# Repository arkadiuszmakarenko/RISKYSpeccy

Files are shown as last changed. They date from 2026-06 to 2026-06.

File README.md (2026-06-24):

# RISKY Speccy

A CH32V307 RISC-V cartridge that plugs into the ZX Spectrum edge connector
and provides:

- **Snapshot loader** — load `.z80` v1/v2/v3 files from USB storage and
  launch them with full register restore.
- **Tape player** — play `.tap` / `.tzx` files by injecting the EAR signal
  directly onto the data bus, compatible with the Spectrum's built-in tape
  loader.
- **Interface 2 ROM cart** — load `.rom` / `.bin` files (up to 16 KB) as an
  Interface 2 style cartridge ROM, mapped into the Spectrum's 0x0000-0x3FFF
  region.
- **On-screen UI** — full-screen file browser and VT100-compatible terminal
  rendered by the CH32 onto the ZX screen via the NMI mailbox, without any
  Z80 cooperation.

See [docs/](docs/) for architecture and subsystem documentation.

---

## Repository layout

```
board/          KiCad schematic and PCB design
docs/           Architecture and subsystem documentation
firmware/       CH32 firmware source
  Core/         WCH RISC-V core support files
  Debug/        UART debug driver
  Ld/           Linker script
  Peripheral/   CH32V30x peripheral drivers
  Startup/      Startup assembly
  User/         Application code (main subsystems)
  zx_src/       Z80-side cart ROM firmware (SDCC)
Makefile        Root build file (builds everything)
```

---

## Building

### Prerequisites

**CH32 RISC-V toolchain** (WCH GCC 12):

Download from [MounRiver Studio](http://www.mounriver.com/) or extract the
standalone toolchain archive.  The default path expected by the Makefile is:

```
~/RISC-V_Embedded_GCC12
```

**Z80 toolchain** (for the `zx_src` sub-firmware):

```
sudo apt install sdcc
```

The `sdasz80` assembler is included with SDCC.  GNU `objcopy`, `od`, and
`awk` must also be available (standard on most Linux systems).

### Build

```sh
make
```

Override the toolchain path if needed:

```sh
make TOOLCHAIN_DIR=/path/to/RISC-V_Embedded_GCC12
```

Useful targets:

```sh
make help                # full list of targets
make build-all-versions  # bootloader + both app variants + combined image
make versions            # show all output artifact paths
make clean
```

Build outputs land in `build/`.

### Continuous integration (GitHub Actions)

A workflow at [`.github/workflows/build.yml`](.github/workflows/build.yml)
builds the firmware on every push, pull request, tag, and manual dispatch.
It:

- installs the WCH RISC-V toolchain (V2.10) and SDCC from `apt`
- runs `make` at the repo root
- verifies that all expected artifacts (`Bootloader.bin`, `RISKYSpeccy.bin`,
  `RISKYZXS.UPD`, `RISKYZXS_COMBINED.bin`) are produced
- checks that the bootloader and app-update binaries fit their respective
  flash regions
- uploads the binaries as a workflow artifact
  (`RISKYZXSpectrum-firmware`, retained for 90 days) and the listings/maps
  as a separate logs artifact
- on tag pushes (`v*`) and on `release` events, attaches the user-facing
  binaries (`*.bin` / `*.UPD` at the top of `build/`) to a GitHub Release

The default `latest` release is marked as prerelease and is updated on
every non-PR run; tagged builds (`v1.2.3`, etc.) become stable releases.
No secrets are required — the workflow uses the default `GITHUB_TOKEN`
to create/update releases.

### Flashing options

| Mode | Command | Output | When to use |
|---|---|---|---|
| **Combined** (default) | `make flash` | `build/RISKYZXS_COMBINED.bin` | Fresh cartridge setup or bootloader + app in one shot |
| **Standalone (no BL)** | `make flash-standalone` | `build/RISKYSpeccy.bin` | Development or single-firmware deployment |
| **Bootloader only** | `make flash-bootloader` | `build/bootloader/Bootloader.bin` | Bootloader maintenance / recovery |
| **App via USB** | _(copy to USB drive)_ | `build/RISKYZXS.UPD` | After bootloader is installed |

The Linux `make flash*` targets drive a **WCH-LinkE** via OpenOCD.

#### Programming on Windows with WCH tools

1. Install [WCHISPTool](https://www.wch.cn/downloads/WCHISPTool_Setup_exe.html)
   and the **WCH-LinkE** USB driver (WCH provides a signed INF/VCP driver
   bundle — let the installer do it, or grab the driver from the
   MounRiver Studio distribution).
2. Connect the **WCH-LinkE** to the cartridge's SWD header (SWDIO / SWCLK /
   GND).  Power the Spectrum so the CH32V307 is alive on the edge connector.
3. Launch **WCHISPTool** and pick the chip family **CH32V30x** (the
   CH32V307 lives in this group).
4. In the device list, select the WCH-LinkE you just plugged in.  The tool
   should show the chip's `Device ID` once it talks to the target.
5. Click **...** next to the file box and point it at the build output:
   - `build/RISKYZXS_COMBINED.bin` — bootloader + application in one shot
     (use the **.bin** image, not `.elf`/`.hex`)
   - `build/RISKYSpeccy.bin` — application only (no bootloader)
   - `build/bootloader/Bootloader.bin` — bootloader only
6. Set the start address to **`0x08000000`** for any of the above.
7. Enable **"Erase before program"** and **"Verify after program"**, then
   click **Download** (or press F5).  Progress shows in the status bar;
   "Success" means programming finished and verified.

#### Updating the application via USB (no programmer)

For the **app-via-USB** path, the bootloader must already be installed on
the cartridge (use the WCHISPTool flow above once with the combined or
bootloader image to put it in place).

1. Copy `build/RISKYZXS.UPD` to the **root** of a **FAT12/FAT16/FAT32**
   formatted USB drive.
2. Insert the USB drive into the cartridge's USB port.
3. To **force IAP mode** (e.g. if the application is wedged and you want
   to reflash), fit a jumper across the **SWDIO / SWCLK** header pins
   before powering on.
4. Power on (or reset) the cartridge. The Ready LED should flash 3 times.
   The bootloader detects the drive and programs the application. If
   programming was successful, the Ready LED will flash slowly 10 times.
   If unsuccessful, it will start rapidly flashing.

See [docs/bootloader.md](docs/bootloader.md) for the full update flow,
state-machine details, and recovery options.

---

## CH32V303 RAM / FLASH split

The CH32V303 lets you trade FLASH for RAM (or vice versa) via the
**SRAM_CODE_MODE** field — bits `[7:6]` of the USER option byte at
`0x1FFFF802`.  The four available splits are:

| SRAM_CODE_MODE | FLASH  | RAM |
|---|---|---|
| `00` | 192 KB | 128 KB |
| `01` | 224 KB |  96 KB |
| `10` | 256 KB |  64 KB |
| `11` | 288 KB |  32 KB |

This project uses **`00`** (192 KB FLASH + 128 KB RAM).  **You must set
this split before flashing the firmware**, otherwise RAM and FLASH regions
will not match the linker script and the firmware will not run.

### Setting the split with WCHISPTool (recommended)

This is the easiest method and requires only the WCH-LinkE programmer.

1. Open **WCHISPTool**, select chip family **CH32V30x**, and connect to the
   target (same as for flashing firmware — see [Flashing options](#flashing-options)).
2. Switch to the **Config** (or **Option Byte**) tab.
3. Locate the **SRAM_CODE_MODE** field (labelled `USER[7:6]` in some
   versions).
4. Select **`00`** from the drop-down to configure 192 KB FLASH + 128 KB RAM.
5. Click **Program** (or **Download**) to write the option byte.
6. Power-cycle or reset the board.  The new split is now active and you can
   proceed to flash the firmware.

### Setting the split with the Makefile (Linux + WCH-LinkE)

The repository provides Makefile targets that set the split and reboot the
chip in one step.  This is the quickest path on Linux.

| Command | Description |
|---|---|
| `make split-info` | Read current option bytes (uses `minichlink -i`) |
| `make split-set` | Set the split to `MODE=0` (192K FLASH + 128K RAM) via minichlink |
| `make split-set MODE=0 SPLIT_TOOL=openocd` | Same, but uses OpenOCD |
| `make split-set-minichlink MODE=N` | Set split via minichlink, `N` = 0..3 |
| `make split-set-openocd MODE=N` | Set split via OpenOCD, `N` = 0..3 |

`MODE` values: `0` = 192K FLASH + 128K RAM, `1` = 224K + 96K, `2` = 256K + 64K,
`3` = 288K + 32K.  **This project requires `MODE=0`.**

```sh
# Default (recommended): mode 0 via minichlink
make split-set

# Mode 0 via OpenOCD
make split-set SPLIT_TOOL=openocd

# Power-cycle the board, then flash firmware
make flash
```

> After writing, power-cycle the board before flashing firmware.

### Setting the split with OpenOCD / WCH-LinkE on Linux (manual)

```sh
openocd -f interface/wch-riscv.cfg \
        -c "init; halt; \
            flash write_word 0x1FFFF802 0xC03F; \
            reset; exit"
```

The half-word `0xC03F` encodes USER byte `0x3F` (`SRAM_CODE_MODE = 00`,
all other bits at default) in the low byte and its complement `0xC0` in
the high byte, as required by the option byte format.

> After writing, power-cycle the board before flashing firmware.

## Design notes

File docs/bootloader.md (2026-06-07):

# Bootloader Architecture

## Overview

The RISKY Speccy bootloader is a specialized in-application programming (IAP) monitor that:

1. **Boots first** from flash offset `0x00000000`
2. **Manages application lifetime** — validates, jumps to, and recovers from invalid application states
3. **Provides USB-based firmware updates** via Petit FatFS + USB MSC
4. **Implements robust USB polling** with automatic attach detection and fallback enumeration
5. **Protects itself** — hard-wired 16 KB memory boundary ensures app writes never corrupt bootloader load image

---

## Memory Map

### Bootloader Regions

```
FLASH Memory (CH32V30x_D8, SRAM_CODE_MODE=00 → 192 KB):
┌─────────────────────────┬─────────────────────────────────────────┐
│ Bootloader              │ Application + IAP Update Slot           │
│ 0x00000000..0x00003FFF  │ 0x00004000..0x0002FFFF                  │
│ (16 KB reserved)        │ (176 KB available)                      │
└─────────────────────────┴─────────────────────────────────────────┘

RAM Memory (128 KB):
┌────────────────────────────────────────────────────────────────┐
│ Stack, data, BSS for bootloader + USB host + FAT subsystems   │
│ 0x20000000..0x2001FFFF                                         │
└────────────────────────────────────────────────────────────────┘
```

> **Note:** Total flash and RAM size are governed by `SRAM_CODE_MODE` (USER[7:6]
> of the option byte at `0x1FFFF802`). The project targets mode `00`
> (192 KB FLASH + 128 KB RAM). All three linker scripts must agree on this
> setting — the chip-wide option byte cannot be different for bootloader and
> application.

### Bootloader Linker Script

**File:** `Bootloader/Ld/Link.ld`

Key settings:

- **BOOT_FLASH:** `ORIGIN=0x00000000, LENGTH=16K` — hard boundary on loadable sections
- **RAM:** `ORIGIN=0x20000000, LENGTH=128K`
- **All `.text`, `.data` LMA mapped to BOOT_FLASH** — linker enforces overflow error if bootloader > 16 KB
- **PROVIDE(`_bootloader_limit` = 0x00004000)** — marks app start boundary
- **PROVIDE(`_flash_limit` = 0x00030000)** — total on-chip flash end (192 KB for `SRAM_CODE_MODE=00`; would be 0x00038000 = 224 KB in mode 01), used by IAP for upper-bound checks on erase/write operations

### Application Linker Script (Bootloader-linked variant)

**File:** `firmware/Ld/Link.ld`

- **FLASH:** `ORIGIN=0x00004000, LENGTH=176K` — app linked with 0x4000 base, fills the rest of the 192 KB flash
- **RAM:** `ORIGIN=0x20000000, LENGTH=128K`
- Final `.data` LMA placed in FLASH for proper ROM image

### Application Linker Script (Standalone variant)

**File:** `firmware/Ld/Link_standalone.ld`

- **FLASH:** `ORIGIN=0x00000000, LENGTH=192K` — full chip, no bootloader
- **RAM:** `ORIGIN=0x20000000, LENGTH=128K`
- Used for development or direct flash without IAP

---

## Boot Flow

### Startup Sequence (main.c)

```
1. Delay_Init()          -- Setup system timer
2. USART_Printf_Init()   -- Configure debug UART
3. Enable GPIOA + AFIO clocks
4. GPIO_PinRemapConfig(SWJ_Disable) -- Release PA13/PA14 from SWD alternate function
5. PA13 → push-pull output, driven LOW
   PA14 → input pull-up
6. Check PA14 level
   └─ PA14 LOW (jumpered to PA13): Enter IAP mode
      ├─ IAP_Initialization()  -- USB host, RCC, global state
      ├─ PA8 → open-drain output (LED)
      ├─ blinkLed()
      └─ IAP_Main_Deal() loop (USB update flow)
   └─ PA14 HIGH (no jumper): Jump to application
      └─ IAP_Jump_APP() 
```

### State Machine (IAP_Main_Deal in usb_host_iap.c)

**Goal:** Read file from USB FAT drive, program to flash, verify, and jump to app.

```
┌─ IAP_USBH_PreDeal()
│  ├─ Check root hub port status
│  ├─ If already attached (hardware flag set) but no connect event fired
│  │  └─ Synthesize connect event (handles pre-inserted drives)
│  ├─ Enumerate device
│  │  ├─ Get descriptor
│  │  ├─ Set device address
│  │  ├─ Get config descriptor
│  │  ├─ Parse MSC interface + bulk endpoints
│  │  └─ Return DEF_SUCCESS or error
│  └─ State → ROOT_DEV_SUCCESS = ready
│
├─ PFF_Check_And_Mount()
│  ├─ Initialize disk subsystem (SCSI READ CAPACITY)
│  ├─ pf_mount() — mount FAT filesystem
│  └─ Return 0 if mounted, else error
│
├─ pf_open("RISKYZXS.UPD")
│  └─ If file not found → retry or wait
│
├─ Read file in chunks
│  ├─ pf_read() with adaptive retries
│  ├─ On FR_DISK_ERR:
│  │  ├─ Reduce chunk size (512 → 256 → 128 → 64 bytes)
│  │  ├─ Reset disk state machine
│  │  ├─ Re-mount filesystem
│  │  ├─ Re-seek to offset
│  │  └─ Retry pf_read()
│  └─ Load into RAM buffer
│
├─ IAP_Flash_Program()
│  ├─ Erase pages as needed
│  ├─ Write aligned 256-byte blocks
│  ├─ Verify keys (flash runaway protection)
│  └─ Return 0 if success
│
├─ Verify by re-opening file
│  ├─ pf_read() entire file again
│  ├─ Compare each byte with flash
│  └─ If match → Vfy OK; else Vfy FAIL
│
└─ If success: IAP_Jump_APP()
   ├─ Set software interrupt (Software_IRQn)
   ├─ Trigger it
   ├─ CPU jumps to app @ 0x08004000
```

---

## USB Host & FAT Integration

### USB Host Stack

**File:** `Bootloader/User/USB_Host/ch32v30x_usbfs_host.c`

- **USBFSH_CheckRootHubPortStatus()** — polls device attachment state
- **USBFSH_EnableRootHubPort()** — waits for post-reset device detection
- **USBFSH_GetDeviceDescr()** — retrieves device descriptor with retries
- **USBFSH_CtrlTransfer()** — sends control requests (SET ADDR, GET CONFIG)
- **USBFSH_SendEndpData() / GetEndpData()** — bulk data transfer with NAK/STALL handling

**Key Tuning:**
- Bulk endpoint timeout: `200 ms` (allows NAK retry without aborting)
- Reset recovery: `DEF_RE_ATTACH_TIMEOUT = 100 ms`

### Petit FatFS Integration

**File:** `Bootloader/User/Pff/diskio.c`

- **disk_initialize()** — SCSI READ CAPACITY to detect drive presence
- **disk_readp()** — sector read with:
  - CBW (Command Block Wrapper) send
  - Data phase
  - CSW (Command Status Wrapper) receive
  - Multi-stage retry on error (TUR, reset, re-init, final fail print with sense data)

**Key Features:**
- Adaptive chunk size: starts at 512 bytes, halves on error
- Sense data logging: prints ASC/ASCQ for SCSI diagnostics
- Geometry detection: logs last LBA and block size on failure

---

## Recovery & Fallback Mechanisms

### Pre-inserted USB Drive Detection

**Problem:** If USB is already in the slot at power-on, the attach interrupt may not fire, leaving the device stuck in idle state.

**Solution (firmware/User/FATFS/usb_disk.c and Bootloader):**
```c
hw_attached = ((USBFSH->MIS_ST & USBFS_UMS_DEV_ATTACH) != 0) ? 1 : 0;
if ((ret == ROOT_DEV_FAILED) && hw_attached &&
    (RootHubDev[usb_port].bStatus != ROOT_DEV_SUCCESS)) {
    ret = ROOT_DEV_CONNECTED;  // Force enum
}
```

### Invalid Application / No Jumper

If the jumper is absent at power-on, the bootloader jumps unconditionally to the application address (`0x08004000`). If no valid firmware is present at that address, the behaviour is undefined — the chip will fault or spin. In this case, refit the jumper and power-cycle to re-enter IAP mode and re-flash.

### Persistent USB Retry Loop

**Problem:** Firmware terminal used to spin `ret=255` infinitely if USB never achieved ready state.

**Solution (firmware/User/zx_terminal.c):**
```c
/* Poll with timeout + adaptive re-init on default state */
for (tries = 0; tries < 100; ++tries) {
    usb_ret = USBH_PreDeal();
    if (usb_ret == DEF_SUCCESS) break;
    Delay_Ms(20u);
}
if (usb_ret == DEF_DEFAULT) {
    ClearUSB();  // Reset state
    USB_Initialization();
    Delay_Ms(50u);
    /* Retry briefly */
    for (tries = 0; tries < 50; ++tries) {
        usb_ret = USBH_PreDeal();
        if (usb_ret == DEF_SUCCESS) break;
        Delay_Ms(20u);
    }
}
```

---

## Build Targets

### Root Makefile (Makefile)

**Key rules:**

| Target | Effect |
|---|---|
| `make bootloader` | Compiles and links Bootloader/.* → build/bootloader/Bootloader.elf/.bin |
| `make app-bootloader` | Links app at 0x4000 → build/RISKYZXS.UPD |
| `make app-standalone` | Links app at 0x0000 → build/RISKYSpeccy.bin |
| `make combine` | Pads to 16 KB + cat bootloader.bin + app.bin → build/RISKYZXS_COMBINED.bin |
| `make all` or `make build-all-versions` | Build all four above |
| `make flash` | Flash combined image to 0x0000 |
| `make flash-bootloader` | Flash bootloader only |
| `make flash-app-upd` | Flash app update image to 0x4000 |
| `make flash-standalone` | Flash standalone app to 0x0000 |

### Bootloader Compile Settings

- **Optimization:** `-Os` (size) to fit 16 KB boundary
- **Debug logs:** Controlled by `DEF_DEBUG_PRINTF` in `Bootloader/User/USB_Host/usb_host_config.h`
- **Compiler flags:** Same RISC-V ABI as app, but no `-Ofast`

---

## Testing & Validation

### Manual Testing Checklist

1. **Boot to IAP with PA13/PA14 jumpered**
   - Fit jumper across SWDIO (PA13) and SWCLK (PA14) header pins
   - `Initializing GPIO for IAP mode detection...` then `Initializing IAP subsystem...` prints on USART1
   - LED blinks
   - Prompt appears on ZX screen

2. **USB enumeration**
   - Insert USB drive with test file
   - Press Enter
   - `USB dev In.` and `USB Port 00 Device Enumeration Succeed` print

3. **File programming**
   - Check `IAP: XXXX bytes` matches file size
   - Verify no read errors or `Len err` prints

4. **Reboot behavior**
   - After successful upgrade, reboot without USB
   - App starts directly (no IAP prompt)
   - LED stops blinking

5. **Recovery from missing/corrupt firmware**
   - Fit the jumper across SWDIO/SWCLK
   - Power-cycle the cartridge
   - Bootloader enters IAP mode (jumper present)
   - Re-flash via USB drive

### Automated Build Validation

```sh
make clean
make build-all-versions
make versions  # Print all artifact paths
# Inspect build/bootloader/Bootloader.siz — should be < 16 KB
# Inspect build/RISKYZXS.UPD — should match firmware size
```

---

## Known Limitations & Future Work

1. **Single USB device** — Only one MSC drive supported at a time
2. **FAT cluster chain** — Petit FatFS may struggle with highly fragmented drives
3. **No rollback** — If verification fails, no automatic revert to previous version
4. **LED blink pattern** — Currently just slow blink; could encode state more clearly (e.g., rapid on error)
5. **Timeout configurable** — USB timeouts are hardcoded; could be made tunable via config sector

---

## References

- CH32V30x Datasheet: `http://www.wch.cn/downloads/CH32V30xRM_PDF.html`
- Petit FatFS: `http://elm-chan.org/fsw/ff/00index_p.html`
- USB Mass Storage Class: USB-IF BOT Specification
- WCH OpenOCD Setup: `http://www.mounriver.com/`

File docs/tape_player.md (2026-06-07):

# Tape Player — TAP and TZX Playback

This document explains how `.tap` and `.tzx` tape image files are loaded and
played back, and how the EAR signal is injected onto the ZX Spectrum data bus
by the CH32V307 cartridge MCU.

---

## Hardware overview

The ZX Spectrum reads the cassette EAR signal via an `IN A,(#FE)` instruction.
The ULA drives the data bus with the current tape level on **bit 6**.  The
cartridge exploits this by intercepting every `IN A,(#FE)` and driving the
data bus itself with the current playback state.

| Signal | GPIO | Direction | Purpose |
|---|---|---|---|
| /IORQ  | GPIOC Pin 8  | Input floating → EXTI9_5 trigger | Fires on every I/O cycle  |
| /RD | GPIOB Pin 5  | Input floating | Distinguishes IN from OUT / INTACK |
| A0 | GPIOE Pin 0  | Input floating | Low = ULA port (tape/keyboard); high = other |
| Data | GPIOD[7:0] | Input / output PP | Driven during IN A,(#FE) only |

**Key principle**: the CH32 does not generate an audio signal — it drives the
Z80 data bus directly.  When the Spectrum ROM tape loader executes
`IN A,(#FE)`, the CH32 asserts the data bus with the current EAR bit value.
The ROM loader reads the bit and advances its own sync/data detection logic
exactly as it would from a real tape.

> **Bus-contention note**: the ULA also drives the data bus during
> `IN A,(#FE)`.  While the IORQ ISR is active there is a brief period of
> contention between the CH32 push-pull output and the ULA output.
> This is an experimental implementation; it is tolerable on hardware that
> accepts brief contention, but not guaranteed safe on all boards.

---

## File formats

### TAP

A `.tap` file is a sequence of raw TAP blocks with no global header.
Each block is:

```
Offset  Size  Content
  0       2   Block length N (little-endian, does not include these 2 bytes)
  2       N   Block data (first byte is the ZX flag byte: 0x00=header, 0xFF=data)
```

The flag byte determines the pilot pulse count:
- `0x00` (program/header block): **8064 full pilot pulses**
- any other value (data block): **3220 full pilot pulses**

### TZX

A `.tzx` file begins with the 10-byte global header:

```
Offset  Size  Content
  0       7   "ZXTape!" (ASCII, no null terminator)
  7       1   0x1A (end-of-text marker)
  8       1   Major version (must be 1)
  9       1   Minor version
```

followed by a sequence of typed blocks.  The player supports:

| Block ID | Name | Handling |
|---|---|---|
| `0x10` | Standard speed data | Converted to a TAP block in memory  |
| `0x20` | Pause | Skipped (converted blocks carry their own inter-block pause) |
| `0x21` | Group start | Skipped (metadata) |
| `0x22` | Group end | Skipped (metadata) |
| `0x30` | Text description | Skipped (metadata) |
| `0x31` | Message block | Skipped (metadata) |
| `0x32` | Archive info | Skipped (metadata) |
| `0x33` | Hardware type | Skipped (metadata) |
| `0x35` | Custom info | Skipped (metadata) |
| `0x5A` | Glue block | Skipped |
| any other | Turbo / pure tone / CSW / direct | **Rejected** — load fails |

TZX conversion is performed in-place inside the 50 KB tape buffer
(`TAP_ConvertTzxInPlace`): standard-speed blocks (`0x10`) are rewritten as
plain TAP blocks at the start of the buffer, metadata blocks are discarded,
and the resulting TAP stream length is stored in `s_tap_total`.

---

## Tape timing

All timings are expressed in **Z80 T-states at 3.5 MHz**.

| Signal segment | Duration (T-states) | TIM2 ticks (×20) |
|---|---:|---:|
| Pilot half-pulse | 2168 | 43 360 |
| Sync first half |  667 | 13 340 |
| Sync second half |  735 | 14 700 |
| Bit-0 half-pulse |  855 | 17 100 |
| Bit-1 half-pulse | 1710 | 34 200 |
| Inter-block pause | ~1 s (≈1660 pilot-half intervals) | — |

**Timer clock**: TIM2 prescaler = 1 (÷2) → 144 MHz / 2 = **72 MHz**.  One
T-state ≈ 72 MHz / 3.5 MHz = **20.57 ticks**, rounded to 20.  The resulting
~3 % timing error is well within the ±10 % tolerance of the ZX ROM tape
loader.

Each bit is transmitted as **two equal half-pulses**: EAR toggles at the start
of the first half and again at the start of the second half.  Bits are sent
**MSB first** within each byte.

---

## State machine

`TAP_TimerISR` (TIM2 one-shot update interrupt, VTF slot 2) drives the
following state machine.  On every fire:
1. The current EAR level (`s_ear_bit`) is toggled (except during `TAP_PAUSE`).
2. The next one-shot period is loaded and TIM2 is restarted.

```
           TAP_IDLE
               │  TAP_Player_Start() + TAP_NextBlock()
               ▼
           TAP_PILOT  ─── decrement s_pilot_half_rem
               │             (8064 × 2 or 3220 × 2 half-pulses)
               │  last half-pulse
               ▼
           TAP_SYNC1  ──► TAP_SYNC2
                               │
                               ▼
                      TAP_DATA_FIRST_HALF ◄────────────────┐
                               │                           │
                               ▼                           │ next bit
                      TAP_DATA_SECOND_HALF ─── advance bit─┘
                               │
                               │  block exhausted
                               ▼
                           TAP_PAUSE  ─── count down ~1 s
                               │
                ┌──────────────┴──────────────┐
                │  more blocks                │  no more blocks
                ▼                             ▼
            TAP_PILOT                     TAP_DONE
                                          (ISRs disabled)
```

---

## Two-ISR architecture

### TAP_TimerISR — EAR signal generator

- **Interrupt**: TIM2 update (one-shot mode), **VTF slot 2**, priority 2.
- **Responsibility**: advance the state machine and toggle `s_ear_bit`.
- **Never** touches the data bus — it only updates the `s_ear_bit` variable.
- Arms the next one-shot by writing `TIM2->ATRLR` and setting `TIM_CEN`.

### TAP_IorqISR — Bus injection

- **Interrupt**: EXTI9_5 on PC8 (`/IORQ` falling edge), **VTF slot 1**, priority 1.
- **Fires** on every Z80 I/O cycle — both IN and OUT.
- **Gate condition**: A0=0 (GPIOE bit 0 low) AND /RD=0 (GPIOB Pin 5 low).
  - A0=0 selects the ZX ULA port `0xFE` (tape + keyboard + border).
  - /RD=0 means this is an `IN` instruction, not `OUT` or interrupt-acknowledge.
- If the gate passes, drives the full 8-bit data bus:

```
Bit 7   1  (reserved / always 1)
Bit 6   s_ear_bit  ← current tape EAR level
Bit 5   1  (reserved / always 1)
Bits 4-0  1  (keyboard rows — all keys reported as not pressed)
```

- Holds the bus driven until `/RD` deasserts, then tristates `GPIOD`.
- If the gate does not pass (OUT, INTACK, or wrong port), just clears the EXTI
  flag and returns immediately.

**Data bus drive sequence**:
```c
GPIOD->CFGLR = 0x33333333;          /* all 8 pins → push-pull output */
GPIOD->OUTDR = (GPIOD->OUTDR & ~0xFF) | data;
while ((GPIOB->INDR & ZX_PIN_RD) == 0) {}   /* hold for duration of read */
GPIOD->CFGLR = 0x44444444;          /* all 8 pins → floating input   */
```

---

## Two-ISR interaction (sequence diagram)

The player runs **two cooperating ISRs**:

- `TAP_TimerISR` (TIM2, VTF slot 2) — *time domain*: advances the state
  machine and toggles `s_ear_bit` at every pilot/sync/data half-pulse.
- `TAP_IorqISR` (EXTI9_5, VTF slot 1) — *bus domain*: drives the current
  `s_ear_bit` onto D0–D7 when the Z80 actually reads `IN A,(#FE)`.

They share **only** the `s_ear_bit` variable — no queue, no lock.  The
TIM2 ISR is responsible for keeping `s_ear_bit` valid; the IORQ ISR
samples it atomically on each Z80 read.

```mermaid
sequenceDiagram
    autonumber
    participant ROM as ZX ROM tape loader
    participant Z as Z80 CPU
    participant E as Edge connector<br/>(A0, D0-D7,<br/>/IORQ, /RD)
    participant IORQ as TAP_IorqISR<br/>(EXTI9_5, VTF slot 1)
    participant TIM as TAP_TimerISR<br/>(TIM2, VTF slot 2)
    participant SM as State machine<br/>s_ear_bit, s_state
    participant CH as CH32 main thread

    Note over CH,SM: Setup (once)
    CH->>CH: ZX_RomcsRelease() — ZX ROM visible
    CH->>Z: ZX_Z80Reset() — boots to BASIC
    Z->>ROM: user types LOAD "" + Enter
    CH->>SM: TAP_Player_Load(path) → parse TAP/TZX
    CH->>CH: TAP_Player_Start()
    CH->>TIM: SetVTFIRQ slot 2 — arm TIM2 one-shot
    CH->>IORQ: SetVTFIRQ slot 1 + NVIC_Enable — arm EXTI9_5
    Note over TIM: pilot half-pulse begins

    Note over TIM,SM: Time domain — state advance
    loop every pilot / sync / data half-pulse (TIM2 one-shot)
        TIM->>SM: read current state (PILOT, SYNC, DATA, PAUSE...)
        TIM->>SM: toggle s_ear_bit (except in PAUSE)
        TIM->>TIM: load TIM2->ATRLR = next half-pulse, restart
    end

    Note over ROM,IORQ: Bus domain — Z80 reads EAR
    ROM->>Z: IN A,(#FE)
    Z->>E: /IORQ LOW, A0 LOW, /RD LOW, A[7:0] = 0xFE
    E->>IORQ: EXTI9_5 fires (PC8 falling edge)
    IORQ->>E: sample A0 (GPIOE bit 0)
    IORQ->>E: sample /RD (GPIOB pin 5)
    alt gate passes (A0=0 AND /RD=0)
        IORQ->>SM: read s_ear_bit
        IORQ->>E: GPIOD PP output, D[7:0] = {1, EAR, 1, 11111b}
        E-->>Z: Z80 latches data byte
        Z-->>ROM: A register = data (EAR in bit 6)
        IORQ->>E: wait /RD HIGH → tristate GPIOD
    else not ULA IN (OUT, INTACK, A0=1)
        IORQ->>E: clear EXTI pending, return
    end

    Note over ROM,SM: ROM advances its own sync/data detection
    Note over ROM: count pilot pulses<br/>wait sync1 + sync2
    Note over ROM: per byte — count 8 EAR transitions
    Note over ROM: CRC + length checks<br/>advance to next block

    Note over TIM,CH: Completion
    TIM->>SM: last block done → TAP_DONE
    TIM->>TIM: NVIC_DisableIRQ(EXTI9_5_IRQn) — IORQ ISR off
    TIM->>CH: TAP_Player_IsRunning() returns 0
    CH->>CH: monitor sees load complete
```

**Why two ISRs and not one?**  The TIM2 ISR is purely a time reference
(it never touches the bus, so it can never collide with the ULA); the
IORQ ISR is purely a bus reaction (it cannot predict the next Z80 read).
A single ISR that did both would have to either guess when the next
half-pulse should end *and* race the ULA for the bus every time, or
block both domains inside one critical section.  Splitting them along
the time/bus axis removes the contention entirely at the cost of a
single shared byte (`s_ear_bit`).

---

## Usage sequence

```
CH32                              Z80 (Spectrum ROM)
─────────────────────────────────────────────────────
ZX_RomcsRelease()           →  ZX ULA ROM appears at 0x0000
ZX_Z80Reset()               →  Z80 boots to BASIC prompt
                               User types: LOAD ""
TAP_Player_Load(path)
                               User presses Enter on UART console
TAP_Player_Start()          →  TIM2 one-shot starts; pilot tone begins
                               IORQ ISR armed
                               ROM tape loader executes IN A,(#FE) loop
                               ISR drives EAR bit per state machine
                               ROM detects pilot → sync → data
                               Program loads into RAM
(TAP_Player_IsRunning() → 0)   Load complete; ISRs disabled automatically
```

> `TAP_Player_IsRunning()` returns 0 when `TAP_DONE` is reached or
> `TAP_Player_Stop()` is called.  The caller in `zx_monitor` polls this to
> know when it is safe to proceed.

---

## Buffer and file limits

| Parameter | Value | Notes |
|---|---|---|
| `TAP_BUF_SIZE` | 50 KB | Covers a complete standard 48 K game .tap  |
| Max TZX block 0x10 data per block | 65535 bytes | 16-bit length field |
| Pilot count (header block) | 8064 full pulses | = 16128 half-pulses |
| Pilot count (data block) | 3220 full pulses | = 6440 half-pulses  |

Files larger than 50 KB are **truncated** with a warning; the player proceeds
with whatever data was read.

---

## Files involved

| File | Role |
|---|---|
| [User/tape_player.c](../User/tape_player.c) | Full implementation: TZX converter, state machine, both ISRs, public API |
| [User/tape_player.h](../User/tape_player.h) | Public API and architecture overview |

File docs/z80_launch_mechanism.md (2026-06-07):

# Z80 Snapshot Launch Mechanism

This document explains, step by step, how a `.z80` snapshot is loaded and
launched on the ZX Spectrum by the CH32V307 cartridge MCU.

Supported snapshot formats:
- **v1** — 30-byte header, flat 49152-byte body (optionally RLE-compressed).
- **v2** — 30-byte base header + 2-byte ext-len + 23-byte ext header + paged blocks.
- **v3** — 30-byte base header + 2-byte ext-len + 54/55-byte ext header + paged blocks.

Hardware modes: 48 K and 128 K/+2 are supported; SamRam, +2A/+3 are rejected.

For the complete CH32↔Z80 pin map (GPIOE / GPIOD / GPIOB / GPIOC assignments,
modes, and active levels), see [zx_bus.md — Hardware connections](zx_bus.md#hardware-connections).

**Key principle**: while ROMCS is driven HIGH by the CH32, the cartridge ROM
(`zxprog`) appears at addresses `0x0000–0x3FFF`.  The cartridge also has a 4 KB
RAM window at `0x3000–0x3FFF` that both the Z80 and the CH32 can access
simultaneously (Z80 via bus, CH32 via `state_pointer->ram[]`).

---

## Phase 1 — Boot: zxprog starts

1. CH32 initialises, configures ROMCS as **push-pull output HIGH**.
2. CH32 pulses `/RESET` LOW for 80 ms then releases it (`ZX_Z80Reset`).
3. Z80 fetches its first opcode from address `0x0000`.  Because ROMCS is HIGH,
   the CH32 cart ISR (`RunCartWithRAM`) serves the byte from `g_zx_image[]`
   (the compiled `zxprog` binary).
4. `zxprog` runs `_startup` (crt0.s):
   - Sets border YELLOW.
   - Enables interrupts (`EI`).
   - Jumps to `main()`.
5. `main()` calls `zx_startup_clear()` — clears all 48 KB of ZX RAM
   (`0x4000–0xFFFF`) and fills the attribute area (`0x5800–0x5AFF`) with
   white paper — then sets border GREEN and enters the **poll loop**.

After ~1200 ms the CH32 returns from `ZX_Z80Reset` and starts the monitor.

---

## Phase 2 — ROM body streaming via NMI mailbox

The CH32 cannot write directly to ZX RAM (it has no DMA to the Z80 bus).
Instead it uses an NMI-based mailbox protocol shared with `zxprog`.

Every NMI command follows the same handshake pattern:
1. CH32 fills the command fields, then atomically increments `*_SEQ`.
2. CH32 pulses the `/INT` line LOW for 40 µs → **NMI fires on Z80**.
3. `_nmi_wrapper` (crt0.s) saves all registers and calls `nmi_handler_c()`.
4. `nmi_handler_c()` dispatches to the appropriate poll handler, executes
   the command, and echoes `*_SEQ` to `*_DONE`.
5. CH32 polls `*_DONE == *_SEQ` to confirm completion.

**Write-command (WCMD) mailbox** — copies data from CH32 into ZX RAM:

```
0x302E  WCMD_SEQ   — CH32 increments to request a write
0x302F  WCMD_DONE  — zxprog echoes SEQ when copy is done
0x3030  DST_LO/HI  — target address in ZX RAM
0x3032  LEN_LO/HI  — byte count (max 512 per chunk)
0x3034  DATA[512]  — payload bytes
```

During snapshot body transfer (`ZX_BusWriteBlock` → `ZX_NmiWriteBlockInternal`)
the CH32 first sets `LOADER_FLAGS` (`0x3F11`, bit 0) to enable the border
animation, and clears it afterwards.  While the flag is set, `wcmd_poll()`
cycles the border through `{BLUE, CYAN, RED, MAGENTA, YELLOW, GREEN}` on each
chunk to provide a visual loading indicator.  The 49 152-byte body
(`0x4000–0xFFFF`) is streamed in 512-byte chunks.

**Paging-command (PGCMD) mailbox** — issues an `OUT (0x7FFD), n` on the Z80:

```
0x302A  PGCMD_SEQ  — CH32 increments to request an OUT
0x302B  PGCMD_DONE — zxprog echoes SEQ when OUT is done
0x302C  PGCMD_VAL  — byte to write to port 0x7FFD
```

Used during v2/v3 128 K body loading to bank in each RAM page before writing
it via WCMD, and once more at the end of loading to lock the correct final
paging state before the launcher fires (see Phase 3c).

**Read-command (RCMD) mailbox** — reads ZX RAM back to CH32:

```
0x3F20  RCMD_SEQ   — CH32 increments to request a read
0x3F21  RCMD_DONE  — zxprog echoes SEQ when copy is done
0x3F22  RCMD_SRC_LO/HI — source address in ZX RAM
0x3F24  RCMD_LEN   — byte count (max 64 per chunk)
0x3F40  RCMD_BUF[64]   — data returned by zxprog
```

**Key mailbox** (ZX → CH32) — reports Z80-side key presses:

```
0x3028  KEY_SEQ    — zxprog increments when a key is pressed
0x3029  KEY_CODE   — ASCII code of the pressed key
```

---

## Phase 3 — Preparing the launcher

Before triggering the jump, the CH32 writes three data structures to the **cart
RAM** window (`0x3000–0x3FFF`) and configures the Z80's interrupt-paging port.
Phases 3a and 3b use `ZX_CartRamWriteBlock` (direct write to
`state_pointer->ram[]`, no NMI needed); Phase 3c uses the PGCMD NMI mailbox.

### 3a — Regblock (`0x3F90`, 26 bytes)

Contains all Z80 CPU registers in the exact order that `_zx_launcher` (crt0.s)
consumes them via a `LD SP, #0x3F90` / `POP` sequence:

| Offset | Bytes | Loaded by |
|---|---|---|
| +0x00  | C', B' | `POP BC` → `EXX` → BC' |
| +0x02  | E', D' | `POP DE` → `EXX` → DE' |
| +0x04  | L', H' | `POP HL` → `EXX` → HL' |
| +0x06  | F', A' | `POP AF` → `EX AF,AF'` → AF' |
| +0x08  | IXl, IXh | `POP IX` |
| +0x0A  | IYl, IYh | `POP IY` |
| +0x0C  | 0x00, I  | `POP AF` → `LD I,A` (A = I value)|
| +0x0E  | border, R_comp | `POP BC` → `OUT(0xFE),C`; `LD R,B` |
| +0x10  | C, B | `POP BC` → main BC |
| +0x12  | E, D | `POP DE` → main DE |
| +0x14  | L, H | `POP HL` → main HL |
| +0x16  | F, A | `POP AF` → main AF |
| +0x18  | SPl, SPh | `LD SP,(0x3FA8)` → user SP |

**R register compensation**: `_zx_launcher` executes exactly **12 M1 cycles**
between `LD R,A` and the user_pc opcode fetch.  Each M1 auto-increments R
(low 7 bits).  The CH32 pre-subtracts 12 so that R reads correctly in the
game:
```
R_comp = ((snapshot_r & 0x7F) - 12) & 0x7F  |  (snapshot_r & 0x80)
```

### 3b — Launcher tail (`0x3FF0`, 6 bytes)

```
0x3FF0  ED          — IM prefix
0x3FF1  46/56/5E    — IM 0 / IM 1 / IM 2 byte
0x3FF2  FB or 00    — EI (if IFF1 was set) or NOP
0x3FF3  C3          — JP
0x3FF4  pc_lo       — low byte of game entry PC
0x3FF5  pc_hi       — high byte of game entry PC
```

### 3c — Port 0x7FFD (via PGCMD NMI)

Immediately before calling `ZX_LaunchZ80`, `Z80_LoadAndRun` sends one final
PGCMD to put the 128 K paging register into the correct state for launch:

| Snapshot type | Value written to 0x7FFD | Effect |
|---|---|---|
| 48 K (all versions) | `0x30` | ROM 1 selected, paging locked |
| 128 K/+2 | `(page_7ffd & 0x3F) \| 0x10` | Snapshot's page + ROM 1 |

This ensures that during the launcher tail execution the 48 K ROM is mapped
at `0x0000–0x3FFF` (ROM 1 = 48 K BASIC ROM), so after ROMCS is tristated
the Z80 can reach the real ROM correctly.

---

## Phase 4 — Arming the ROMCS handover

Inside `ZX_LaunchZ80` (called from `Z80_LoadAndRun`), the CH32 arms the
handover by writing to the `handover_addr` field of the shared `ZXCartState`
struct.  The NVIC is briefly disabled to ensure the ISR cannot observe a
partially-updated value:

```c
/* Inside ZX_LaunchZ80: */
NVIC_DisableIRQ(EXTI15_10_IRQn);
state_pointer->handover_addr = ZX_LAUNCHER_HANDOVER;  /* 0x3FF5 */
NVIC_EnableIRQ(EXTI15_10_IRQn);
```

This tells the cart ISR: *after you have served the read of address `0x3FF5`
(the JP pc_hi byte — the very last byte of the launcher tail), tristate
ROMS and shut yourself down.*

```c
/* Inside RunCartWithRAM (fast ISR), RAM read path: */
if (address == sp->handover_addr) {
    sp->handover_addr = 0xFFFFu;
    /* ROMCS (PB3) → input-floating: ZX ULA now controls ROM selection */
    GPIOB->CFGLR = (GPIOB->CFGLR & ~(0xFu << 12)) | (0x4u << 12);
    EXTI->INTENR &= ~sp->IRQLine;
    NVIC_DisableIRQ(EXTI15_10_IRQn);
}
```

**Why 0x3FF5?**  The Z80 fetches the JP instruction in three memory reads:
`C3` (0x3FF3), `pc_lo` (0x3FF4), `pc_hi` (0x3FF5).  After the third read the
Z80 jumps to `user_pc`.  Releasing ROMCS immediately after 0x3FF5 is the
latest possible moment that is still guaranteed to be in cart space, and the
earliest moment at which the cartridge is no longer needed.

---

## Phase 5 — Firing the launcher

1. CH32 clears `LAUNCHER_ALIVE` (`0x3FAA = 0x00`).
2. CH32 writes `LAUNCH_TRIGGER = 0x55` to `0x3F10` (direct cart RAM write).
3. **On the Z80 side**: next time the `main()` poll loop runs it reads
   `LAUNCH_TRIGGER == 0x55` and calls `zx_launcher()` (→ `_zx_launcher` in
   crt0.s).
4. `_zx_launcher`:
   - `DI` — prevents IM1 from corrupting the stack during register restore.
   - Sets border **WHITE** (visual confirmation on screen).
   - Writes `0xAA` to `LAUNCHER_ALIVE` (`0x3FAA`) — CH32 polls this.
   - `LD SP, #0x3F90` and POPs all registers from the regblock (see Phase 3a).
   - `LD SP, (0x3FA8)` — restores user stack pointer.
   - `JP 0x3FF0` — enters the launcher tail.

---

## Phase 6 — Launcher tail and ROMCS tristate (the handover)

The Z80 executes the launcher tail at `0x3FF0` still served by the cart ISR:

```
0x3FF0  ED xx   — sets interrupt mode (IM 0/1/2)
0x3FF2  FB/00   — EI or NOP (restores IFF1)
0x3FF3  C3      — JP
0x3FF4  pc_lo   — \
0x3FF5  pc_hi   —  ← cart ISR fires handover HERE
```

When the ISR serves the `pc_hi` byte at `0x3FF5`:
- ROMCS is switched to **input-floating** (tristate) in the same ISR invocation,
  before the byte is even latched off the bus.
- The cart EXTI interrupt is disabled.
- The data bus is already back to input state (driven only during the read).

The Z80 now executes `JP user_pc`.  From this point:
- Addresses `0x4000–0xFFFF` are game RAM — no ROMCS involvement.
- Addresses `0x0000–0x3FFF` are served by the **ZX Spectrum's internal ROM**
  (the ULA drives ROMCS LOW for those accesses, as normal).
- The cart MCU is entirely invisible to the Z80.

---

## Phase 7 — CH32 confirms launch and returns

Back on the CH32, `ZX_LaunchZ80` polls:

```c
while (state_pointer->ram[0x0FAA] != 0xAAu) {
    Delay_Ms(1u);
    if (++waited >= 3000u) { /* timeout error */ }
}
printf("z80: launched (alive in %lu ms)\n", waited);
```

`state_pointer->ram[0x0FAA]` is the CH32's direct view of cart RAM address
`0x3FAA`.  The 0xAA byte is written by `_zx_launcher` before the register
restore (Phase 5, step 4), so the CH32 sees it within ~1 ms of the trigger.
The ROMCS handover happens a few microseconds later inside the ISR.

---

## Launch sequence (overview)

The same flow as the ASCII timeline below, but as a sequence diagram so
the mailbox exchanges and the ROMCS handover are easier to follow.

```mermaid
sequenceDiagram
    autonumber
    participant C as CH32 (RISC-V)
    participant N as Cart RAM<br/>(0x3000-0x3FFF)
    participant Z as Z80 (zxprog / _zx_launcher)
    participant U as ZX ULA + ROM

    Note over C,Z: Phase 1 — Boot
    C->>Z: /RESET LOW 80 ms, then release
    C->>C: PB3 ROMCS = HIGH (cart ROM selected)
    Z->>C: MREQ falls on 0x0000
    C-->>Z: drive g_zx_image[0x0000] on D0-D7
    Note over Z: zxprog runs _startup, EI, main()

    Note over C,Z: Phase 2 — Snapshot body (49 KB) via WCMD NMI
    C->>N: write 512-byte body chunk (direct, no NMI)
    C->>N: set LOADER_FLAGS bit 0 (border anim)
    C->>N: WCMD_SEQ++, WCMD_DST, WCMD_LEN
    C->>Z: /INT LOW 40 µs → NMI fires
    Z->>N: wcmd_poll copies chunk into ZX RAM
    Z-->>C: WCMD_DONE echoes SEQ
    Note over C: repeats 96× for full 48K body,<br/>border cycles {BLUE,CYAN,RED,MAG,YEL,GRN}

    Note over C,Z: Phase 2b — 128K paging (per RAM page)
    C->>N: PGCMD_SEQ++, PGCMD_VAL = page byte
    C->>Z: NMI fires
    Z->>U: OUT (0x7FFD), PGCMD_VAL
    Z-->>C: PGCMD_DONE echoes SEQ

    Note over C,Z: Phase 3a/3b — Direct cart-RAM writes
    C->>N: REGBLOCK (26 B at 0x3F90) — direct
    C->>N: LAUNCHER_TAIL (6 B at 0x3FF0) — direct
    C->>N: LAUNCHER_ALIVE = 0x00, then TRIGGER = 0x55

    Note over C,Z: Phase 4-6 — Launcher fires
    Note over Z: DI<br/>border WHITE<br/>ALIVE ← 0xAA
    Z->>N: _zx_launcher reads regblock + tail
    Z->>C: ISR serves 0x3FF5 (pc_hi)
    C->>C: ROMCS → input-floating (tristate)<br/>EXTI15_10 disabled
    Z->>U: JP user_pc — game starts
    Z->>U: subsequent 0x0000-0x3FFF reads served by ZX ROM

    Note over C: Phase 7 — Confirm
    C->>N: poll ALIVE == 0xAA
    C-->>C: ZX_LaunchZ80 returns 1
```

For the byte-accurate ASCII timeline (with border colours and the
NVIC-disable windows in the handover) see the next section.

---

## Summary timeline

```
CH32                                       Z80 (zxprog / _zx_launcher)
──────────────────────────────────────────────────────────────────────
ZX_Z80Reset()                   →  Z80 reset, runs zxprog startup
                                    border YELLOW → startup_clear → border GREEN
ZX_BusWriteBlock (NMI WCMD loop,
  LOADER_FLAG_BORDER_ANIM set)  →  NMI: wcmd_poll copies body chunks
                                    border cycles {BLUE,CYAN,RED,MAGENTA,YEL,GRN}
LOADER_FLAG_BORDER_ANIM cleared
ZX_128kPage (NMI PGCMD,
  0x7FFD=0x30 or snap value)   →  NMI: pgcmd_poll does OUT(0x7FFD)
ZX_CartRamWriteBlock(regblock)     (direct, no NMI)
ZX_CartRamWriteBlock(tail)         (direct, no NMI)
handover_addr = 0x3FF5             (NVIC disabled briefly)
ZX_CartRamWriteBlock(ALIVE=0)      (direct, no NMI)
ZX_CartRamWriteBlock(TRIGGER=0x55) →  poll loop detects → calls _zx_launcher
                                       DI; border WHITE; ALIVE←0xAA
                                       restore regs; JP 0x3FF0
poll ALIVE==0xAA ✓                     executing tail at 0x3FF0..0x3FF5
    ISR serves 0x3FF5 →
        ROMCS tristated ✓
        EXTI disabled ✓
                                       JP user_pc → GAME RUNNING
ZX_LaunchZ80 returns 1
```

---

## Snapshot processing pipeline (`Z80_LoadAndRun`)

The diagram above shows what happens *on the wires*.  This one shows the
**CH32-side processing** of a `.z80` file from the moment the user types
its name at the terminal prompt until the launcher fires.  It is a
flowchart of the `Z80_LoadAndRun()` function in
[User/z80_loader.c](../User/z80_loader.c).

```mermaid
flowchart TD
    A([User picks .z80 file in<br/>zx_terminal / LOAD command]) --> B[Z80_LoadAndRun path]
    B --> C{z80_open_and_parse}
    C -->|FR_OK| D[z80_parse_base_header<br/>30 bytes]
    D --> E{PC == 0?}
    E -->|yes v2/v3| F[z80_read_ext_header<br/>+2 len, +23/54/55 ext]
    E -->|no v1| G[Mark v1, hw_mode = 48K]
    F --> H{z80_is_48k?}
    G --> H
    H -->|no| X1([Reject: SamRam/+2A/+3])
    H -->|yes| I[Set LOADER_FLAGS bit 0<br/>border anim on]

    I --> J{v1?}
    J -->|v1 raw| K[z80_stream_body<br/>flat 49152 B<br/>512-B WCMD chunks x96]
    J -->|v1 RLE| L[z80_rle_decompress<br/>into out_buf<br/>then stream via WCMD]
    J -->|v2/v3| M[z80_stream_v2v3_body<br/>dispatch 16K pages<br/>PGCMD page + WCMD body]

    K --> N[Clear LOADER_FLAGS]
    L --> N
    M --> N
    N --> O[Build ZX_Z80State<br/>from Z80Header]
    O --> P{128K snapshot?}
    P -->|no| Q1[pval = 0x30<br/>ROM1 + lock]
    P -->|yes| Q2[pval = page_7ffd and 0x3F or 0x10<br/>ROM1 + snapshot page]
    Q1 --> R[ZX_128kPage via PGCMD NMI]
    Q2 --> R
    R --> S[ZX_LaunchZ80 and state]
    S --> T([Go to Phase 4-6<br/>launch sequence])

    classDef reject fill:#ffe1e1,stroke:#c00,stroke-width:1px;
    classDef start  fill:#e1f0ff,stroke:#0366d6,stroke-width:2px;
    classDef finish fill:#d4f4dd,stroke:#2a7,stroke-width:2px;
    class X1 reject
    class A start
    class T finish
```

**Key stages**:

1. **Parse** — `z80_open_and_parse` opens the file on the SD card (FatFs),
   reads the 30-byte base header, and (if `PC == 0`, the v2/v3 marker)
   reads the extended header.  Non-48K hardware modes (SamRam, +2A, +3)
   are rejected by `z80_is_48k`.
2. **Border animation** — `LOADER_FLAGS` bit 0 is set before the body
   stream and cleared after, so `wcmd_poll` cycles the border only during
   the actual snapshot body transfer.
3. **Body streaming** — three paths:
   - **v1 raw**: 96 × 512-byte WCMD chunks to `0x4000..0xFFFF`.
   - **v1 RLE**: decompress into a 49 KB staging buffer, then stream the
     same way.
   - **v2/v3 paged**: for each 16 KB page, optionally issue a PGCMD
     (`OUT (0x7FFD), page`) to bank it in, then WCMD the body.  128K
     snapshots use up to 8 pages.
4. **State build** — the parsed `Z80Header` is mapped into the
   `ZX_Z80State` struct that `ZX_LaunchZ80` consumes to build the
   regblock at `0x3F90`.
5. **Final paging** — one last `ZX_128kPage` (PGCMD NMI) sets `0x7FFD`
   to the correct launch value: `0x30` for 48K (ROM1 + lock), or
   `(page_7ffd & 0x3F) | 0x10` for 128K (ROM1 + snapshot page).
6. **Launch** — `ZX_LaunchZ80` writes regblock + tail directly to cart
   RAM, arms `handover_addr = 0x3FF5`, writes `TRIGGER = 0x55`, and
   waits for `ALIVE == 0xAA` — handing off to the sequence diagram
   above.

---

## Cart RAM layout

Full mailbox and data map for the 4 KB cart RAM window (`0x3000–0x3FFF`):

```
0x3000–0x3029   BRIDGE_TEXT  bridge text buffer (40 bytes) — see zx_terminal.md
0x3028          KEY_SEQ        Z80→CH32 key event sequence
0x3029          KEY_CODE       ASCII code of last key pressed
0x302A          PGCMD_SEQ  *   CH32→Z80 port 0x7FFD command sequence (load only)
0x302B          PGCMD_DONE *   Z80 echo when OUT is done (load only)
0x302C          PGCMD_VAL  *   byte to write to port 0x7FFD (load only)
0x302A          VIEW_SEQ   *   CH32→Z80 RAM viewer sequence (post-launch only)
0x302B          VIEW_ADDR_LO   low byte of viewer start address
0x302C          VIEW_ADDR_HI   high byte of viewer start address
0x302D          VIEW_LEN       byte count (max 16)
0x302E          WCMD_SEQ       CH32→Z80 write-block command sequence
0x302F          WCMD_DONE      Z80 echo when copy is done
0x3030–0x3031   WCMD_DST       target address in ZX RAM (little-endian)
0x3032–0x3033   WCMD_LEN       byte count (little-endian, max 512)
0x3034–0x3233   WCMD_DATA      512-byte payload buffer
0x3F00–0x3F01   BSS            zxprog static data (wcmd_last_seq, rcmd_last_seq)
0x3F02          CTRL_FLAGS     bit 0 = ZX_CTRL_DRAW_SUSPEND
0x3F10          LAUNCH_TRIGGER CH32 writes 0x55 to fire the launcher
0x3F11          LOADER_FLAGS   bit 0 = enable loading border animation
0x3F20          RCMD_SEQ       CH32→Z80 read-block command sequence
0x3F21          RCMD_DONE      Z80 echo when copy is done
0x3F22–0x3F23   RCMD_SRC       source address in ZX RAM (little-endian)
0x3F24          RCMD_LEN       byte count (max 64)
0x3F40–0x3F7F   RCMD_BUF       64-byte read-back buffer
0x3F90–0x3FA9   REGBLOCK       26-byte CPU register block for _zx_launcher
0x3FAA          LAUNCHER_ALIVE launcher writes 0xAA when running
0x3FF0–0x3FF5   LAUNCHER_TAIL  [ED, IM_byte, EI/NOP, C3, pc_lo, pc_hi]
```

> **Mutual exclusivity (PGCMD vs VIEW):** `0x302A–0x302C` is shared between
> the **PGCMD** mailbox (snapshot loading, Phase 3c) and the **VIEW**
> mailbox (RAM viewer, post-launch). They are time-sequenced: the CH32
> only drives PGCMD_SEQ during a `.z80` launch, and the terminal only
> drives VIEW_SEQ after the launcher has handed ROMCS back. See
> [zx_terminal.md — RAM viewer](zx_terminal.md#ram-viewer-zxview).

---

## Files involved

| File | Role |
|---|---|
| [User/zx_bus.c](../User/zx_bus.c) | `RunCartWithRAM` ISR (handover), `ZX_LaunchZ80`, `ZX_RomcsRelease` |
| [User/zx_bus.h](../User/zx_bus.h) | `ZX_Z80State` struct, `ZX_LaunchZ80` declaration |
| [User/z80_loader.c](../User/z80_loader.c) | Parses `.z80` header, streams body, calls `ZX_LaunchZ80` |
| [zx_src/zxprog.c](../zx_src/zxprog.c) | Z80-side poll loop, LAUNCH_TRIGGER check |
| [zx_src/crt0.s](../zx_src/crt0.s) | `_zx_launcher`: register restore and jump to game |

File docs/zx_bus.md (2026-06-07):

# CH32–ZX Spectrum Bus Interface

This document explains how the CH32V307 cartridge MCU connects to the ZX
Spectrum Z80 bus at the hardware level, how the `RunCartWithRAM` ISR serves
memory accesses, and what each higher-level bus function does.

---

## Hardware connections

The CH32V307 is wired directly to the ZX Spectrum edge connector.  All bus
signals are sampled or driven by standard GPIO registers without any glue
logic.

### Address bus — GPIOE[15:0]

All 16 address lines are wired to GPIOE pins 0–15.  The address is captured
as a single 16-bit word with `(uint16_t)GPIOE->INDR` at ISR entry.  All
GPIOE pins are configured as input-floating (CNF=01, MODE=00) and never
driven by the CH32.

### Data bus — GPIOD[7:0]

Data lines D0–D7 are wired to GPIOD pins 0–7.

- **Input** (default): `GPIOD->CFGLR = 0x44444444` — all 8 pins floating.
- **Output** (ROM/RAM read): `GPIOD->CFGLR = 0x33333333` — all 8 pins
  push-pull 50 MHz.

The CH32 drives the bus only for the duration of a confirmed read cycle and
tristates it immediately when `/RD` deasserts.

### Control signals — GPIOB

| Signal | Pin | Mode | Active |
|---|-----|---|---|
| ROMCS  | PB3 | PP output (idle HIGH) | HIGH = cart ROM selected |
| /WR | PB4 | Floating input | LOW |
| /RD | PB5 | Floating input | LOW |
| BUSACK | PB6 | Floating input | LOW |
| BUSREQ | PB7 | OD output (idle HIGH) | LOW |
| HALT | PB8 | (not currently used) | — |
| M1 | PB9 | (not currently used) | — |
| /MREQ  | PB10 | IPU input → EXTI15_10 trigger | LOW |
| RESH | PB11 | (not currently used) | — |
| /INT | PB12 | OD output (idle HIGH) | LOW = NMI trigger |
| CK_INV | PB13 | Floating input | clock reference |

### Other control signals

| Signal | Pin | Mode | Notes |
|---|-----|---|---|
| /RESET | PC6 | IPU (pulse OD LOW to reset) | Z80 hardware reset |
| /WAIT  | PC7 | (not currently used) | — |
| /IORQ  | PC8 | Floating → EXTI9_5 (tape player only) | LOW = I/O cycle |
| BDIR | PC9 | OD output | (not currently used) |

---

## Bus architecture

The CH32V307 and the Z80 share the cartridge edge connector as a
**dual-ported** system: the CH32 owns the data/address bus during cart
accesses, while the ZX ULA owns it the rest of the time. The cart RAM
window (`0x3000–0x3FFF`) is a true shared region — both sides read and
write the same physical bytes.

```mermaid
sequenceDiagram
    autonumber
    participant Z as Z80 CPU
    participant E as Edge Connector<br/>(A0-A15, D0-D7,<br/>/MREQ, /RD, /WR)
    participant ISR as RunCartWithRAM ISR<br/>(VTF slot 0, EXTI15_10)
    participant MEM as ZX_Z80State<br/>g_zx_image[16K] / ram[4K]
    participant CH as CH32 main thread

    Note over Z,CH: ROM read (0x0000–0x2FFF)
    Z->>E: assert /MREQ LOW, /RD LOW, A[15:0]
    E->>ISR: EXTI15_10 fires (PE0-15 = address)
    ISR->>MEM: read g_zx_image[address]
    ISR->>E: drive D[7:0] = ROM byte (GPIOD PP)
    ISR-->>Z: Z80 latches data
    ISR->>E: /RD HIGH → tristate D[7:0]

    Note over Z,CH: Cart RAM read (0x3000–0x3FFF)
    Z->>E: assert /MREQ LOW, /RD LOW, A[15:0]
    E->>ISR: EXTI15_10 fires
    ISR->>MEM: read ram[address - 0x3000]
    ISR->>E: drive D[7:0] = RAM byte
    ISR-->>Z: Z80 latches data
    ISR->>E: /RD HIGH → tristate D[7:0]
    Note over ISR: check handover_addr<br/>(ROMCS release if match)

    Note over Z,CH: Cart RAM write (0x3000–0x3FFF)
    Z->>E: assert /MREQ LOW, /WR LOW, A[15:0], D[7:0]
    E->>ISR: EXTI15_10 fires
    ISR->>E: wait /WR LOW (data stable on D[7:0])
    ISR->>MEM: ram[address - 0x3000] = GPIOD->INDR
    ISR-->>E: /MREQ HIGH → clear EXTI pending, return

    Note over Z,CH: CH32 mailbox write (WCMD / PGCMD)
    CH->>MEM: NVIC disable → write ram[] directly
    CH->>MEM: NVIC enable
    CH->>E: pulse /INT LOW 40 µs (NMI trigger, PB12 OD)
    E->>Z: NMI fires → zxprog wcmd_poll()
    Z->>MEM: read WCMD fields, copy data to ZX RAM
    Z->>MEM: write WCMD_DONE = WCMD_SEQ
    CH->>MEM: poll WCMD_DONE == WCMD_SEQ (500 µs retry)
```

Key points the diagram shows:

- **The Z80 bus signals are sampled, not bridged.** Every edge-connector
  signal that matters (A0–A15, D0–7, /MREQ, /RD, /WR, /RESET) is wired
  directly to a CH32 GPIO. There is no external latch or transceiver.
- **`RunCartWithRAM` is the bus arbiter.** It runs on every /MREQ falling
  edge (VTF slot 0, highest priority) and decides whether the CH32 must
  drive the data bus (cart ROM / cart RAM read) or capture it (cart RAM
  write). All other CH32 work is interrupted during this window.
- **The cart RAM window is the shared mailbox region.** Both the Z80 (via
  its bus cycles) and the CH32 (via `state_pointer->ram[]`) can read or
  write the same 4 KB physical bytes — see
  [Cart RAM layout](z80_launch_mechanism.md#cart-ram-layout) for the full
  map.

---

## ISR: `RunCartWithRAM`

This is the hot-path ISR that runs on every Z80 memory access.  It is
registered as a **VTF (Vector Table Free) fast interrupt** in NVIC slot 0
via `SetVTFIRQ` so that entry latency is minimised — there is no function
prologue and no stack frame.  The function carries
`__attribute__((interrupt("WCH-Interrupt-fast")))`.

EXTI line 10 (PB10 = /MREQ) is configured as a **falling-edge** trigger.
Every time the Z80 asserts /MREQ the ISR fires, regardless of whether the
access is a ROM read, RAM read, RAM write, or to an unselected address.

### ISR decision tree

```
/MREQ falls → EXTI15_10_IRQn fires
│
├─ /RD == LOW?  ──────── YES ──────────────────────────────────────────┐
│                                                                       │
│   address < RamBase (0x3000)?                                        │
│   ├─ YES → ROM read                                                  │
│   │        drive data = g_zx_image[address]                         │
│   │        wait /RD HIGH, tristate                                   │
│   │                                                                  │
│   └─ NO → address <= RomLast (0x3FFF)?                              │
│           ├─ YES → Cart RAM read                                     │
│           │        drive data = ram[address - RamBase]               │
│           │        wait /RD HIGH, tristate                           │
│           │        check handover_addr → tristate ROMCS if match    │
│           └─ NO  → ignore (not our address range)                   │
│                                                                       │
└─ /RD == HIGH ────────────────────────────────────────────────────────┘
   Wait for /MREQ+/WR both LOW  (write cycle detection)
   ├─ /WR asserts while /MREQ held?
   │   ├─ YES → address in cart RAM range?
   │   │        ├─ YES → capture data = GPIOD->INDR & 0xFF
   │   │        │        loop while /WR LOW (capture last stable value)
   │   │        │        write to ram[address - RamBase]
   │   │        └─ NO  → ignore
   │   └─ NO  → /MREQ de-asserted before /WR (e.g. opcode fetch M1
   │            where /WR never asserts) → ignore
   │
   Clear EXTI_Line10 pending flag; return
```

### Read path — ROM (0x0000–0x2FFF)

```c
GPIOD->CFGLR = sp->BusOn;          /* PP output */
GPIOD->OUTDR = (GPIOD->OUTDR & ~sp->DataMask) | g_zx_image[address];
while ((GPIOB->INDR & sp->PinRD) == 0u) {}   /* hold until /RD HIGH */
GPIOD->CFGLR = sp->BusOff;         /* floating input */
```

`g_zx_image[]` is the compiled `zxprog` binary embedded as a C array in
flash.  It is 16 KB (`0x0000–0x3FFF`) but only the lower 12 KB
(`0x0000–0x2FFF`) is pure ROM; `0x3000–0x3FFF` is cart RAM.

### Read path — Cart RAM (0x3000–0x3FFF)

Identical to the ROM path except the source is `sp->ram[address - sp->RamBase]`.
After the read completes, the ISR checks whether `address == sp->handover_addr`:
if so it tristates ROMCS and disables itself (snapshot launch handover — see
[z80_launch_mechanism.md](z80_launch_mechanism.md)).

### Write path — Cart RAM

```c
/* Wait until /WR asserts while /MREQ is still held */
while (((GPIOB->INDR & sp->PinMREQ) == 0u) &&
       ((GPIOB->INDR & sp->PinWR)   != 0u)) {}

if (((GPIOB->INDR & sp->PinMREQ) == 0u) &&
    ((GPIOB->INDR & sp->PinWR)   == 0u)) {
    if (address in cart RAM range) {
        GPIOD->CFGLR = sp->BusOff;   /* ensure data bus is input */
        do {
            sp->ram[address - sp->RamBase] = (uint8_t)(GPIOD->INDR & sp->DataMask);
        } while ((GPIOB->INDR & sp->PinWR) == 0u);
    }
}
```

The data is sampled repeatedly while /WR is held to capture the stable
value.  The data bus is kept floating throughout (the Z80 drives it).

---

## ROMCS control

ROMCS (PB3) selects whether the ZX Spectrum sees the cartridge ROM or its
own internal ROM at `0x0000–0x3FFF`.

| State | PB3 mode | Effect |
|---|---|---|
| Cart ROM active | Push-pull HIGH | CH32 ISR serves all `0x0000–0x3FFF` reads |
| Cart ROM released | Input-floating | ZX ULA drives ROMCS normally; internal ROM visible |

**`ZX_RomcsAssert()`** — re-configures PB3 as push-pull HIGH, re-arms the
EXTI vector, and re-enables the NVIC line.  Used before `ZX_Z80Reset()` to
ensure zxprog boots.

**`ZX_RomcsRelease()`** — switches PB3 to input-floating and stops the ISR.
Used before tape playback so the Spectrum's own ROM is available for the
BASIC tape loader.

---

## Z80 reset — `ZX_Z80Reset()`

```
PC6 → OD output, pulled LOW    ← /RESET asserted (80 ms)
PC6 → OD output, released HIGH ← /RESET released
PC6 → IPU input                ← passive monitoring
Delay 1200 ms                  ← wait for zxprog to clear 48 KB RAM
```

The open-drain drive on PC6 allows the cartridge to pull /RESET LOW without
conflicting with the Spectrum's own RC pull-up.  The 1200 ms delay ensures
`zxprog`'s startup RAM clear is complete before any mailbox traffic begins.

---

## NMI trigger — `ZX_TriggerNMI()`

The CH32 triggers an NMI on the Z80 by pulsing `/INT` (PB12, open-drain)
LOW for 40 µs.  Before the pulse it waits for a ZX clock edge (GPIOB.13
inverted clock) to synchronise with the Z80 clock and avoid a pulse that
straddles a cycle boundary.

```c
ZX_WaitClockToggle(ZX_BUS_TIMEOUT);   /* sync to Z80 clock edge */
GPIO_ResetBits(GPIOB, ZX_PIN_INT);    /* pull /INT LOW */
Delay_Us(40u);
GPIO_SetBits(GPIOB, ZX_PIN_INT);      /* release */
```

Despite the signal being labelled `/INT`, the ZX Spectrum NMI hardware uses
this pin as its NMI source.

---

## Higher-level bus operations

### `ZX_BusWriteBlock` — NMI WCMD mailbox write

Writes an arbitrary range of ZX RAM (`0x4000–0xFFFF`) using the NMI mailbox
protocol.  Calls `ZX_NmiWriteBlockInternal` in 512-byte chunks.

For each chunk:
1. Copies payload into `state_pointer->ram[WCMD_DATA - 0x3000]` (direct cart
   RAM write — no bus cycle needed).
2. Writes `WCMD_DST`, `WCMD_LEN`, then increments `WCMD_SEQ`.
3. Calls `ZX_TriggerNMI()`.
4. Polls `WCMD_DONE == WCMD_SEQ` (with 500 µs retry, 200 ms timeout).

The Z80 `nmi_handler_c` → `wcmd_poll()` copies the data from cart RAM to the
target ZX RAM address and echoes the sequence number.

### `ZX_BusReadBlock` — NMI RCMD mailbox read

Reads an arbitrary range of ZX RAM back to the CH32 using the RCMD mailbox
in 64-byte chunks.  Same handshake as WCMD but reversed direction:
zxprog copies the requested bytes into `RCMD_BUF` in cart RAM.

### `ZX_CartRamWriteBlock` / `ZX_CartRamReadBlock` — direct cart RAM

Reads or writes the 4 KB cart RAM window (`0x3000–0x3FFF`) directly via
`state_pointer->ram[]` without triggering an NMI.  The NVIC is briefly
disabled during each transfer to prevent the ISR from concurrently modifying
the same bytes.

```c
NVIC_DisableIRQ(EXTI15_10_IRQn);
for (i = 0; i < length; ++i)
    ram[address - RamBase + i] = buffer[i];
NVIC_EnableIRQ(EXTI15_10_IRQn);
```

Used for all mailbox setup (WCMD, RCMD, PGCMD, LAUNCH_TRIGGER, REGBLOCK,
LAUNCHER_TAIL) where the data must be ready before the NMI fires.

### `ZX_KeyPoll` — read Z80 keyboard events

Reads `KEY_SEQ` (`0x3028`) from cart RAM via `ZX_CartRamReadBlock`.  If the
sequence number has changed since the last call, it also reads `KEY_CODE`
(`0x3029`) and returns the new key code.

---

## `ZXCartState` structure

A single static instance (`s_state`) is used for the lifetime of the firmware.
`state_pointer` is set to `&s_state` by `Init_Cart()` and must not be NULL
before any ISR or bus function runs.

```
struct ZXCartState {
    BusOn       — 0x33333333: CFGLR value to switch GPIOD to PP output
    BusOff      — 0x44444444: CFGLR value to switch GPIOD to floating input
    DataMask    — 0x000000FF: mask for reading GPIOD->INDR (8 data bits)
    RamBase     — 0x3000:  lowest cart RAM address
    RomLast     — 0x3FFF:  highest address served by the cart ISR
    PinRD       — GPIO_Pin_5  (PB5)
    PinWR       — GPIO_Pin_4  (PB4)
    PinMREQ     — GPIO_Pin_10 (PB10)
    IRQLine     — EXTI_Line10
    handover_addr — 0xFFFF (inactive) or 0x3FF5 (launcher armed)
    ram[0x1000] — 4 KB mirror of the ZX cart RAM window 0x3000–0x3FFF
}
```

The `ram[]` array is simultaneously:
- The **source** served to the Z80 for cart RAM reads.
- The **sink** written by the Z80 for cart RAM writes.
- The **mailbox** area accessed directly by the CH32 (`ZX_CartRamWriteBlock`).

Both the ISR and the CH32 main thread access `ram[]` concurrently.  The CH32
uses NVIC disable/enable guards around its own accesses; the ISR does not need
a guard because it runs at higher priority and is inherently atomic per access.

---

## Timing constraints

| Parameter | Value | Notes |
|---|---|---|
| EXTI→ISR latency (VTF fast) | ~3–5 ns | No stack frame, no prologue |
| Z80 clock (3.5 MHz) | 285 ns / T-state | One T-state = ~285 ns |
| Minimum /MREQ LOW window | 2–3 T-states | ISR must complete within this window |
| CH32 core clock | 144 MHz | ~7 ns/cycle |
| NMI pulse width | 40 µs | >> one Z80 machine cycle |

The ISR is compiled with `-Ofast` (`#pragma GCC optimize("Ofast")`) to ensure
the read path completes before the Z80 de-asserts /RD.  Any function called
from the hot path (data bus drive, tristate) is declared `static inline` or
placed in the same translation unit to avoid call overhead.

---

## Initialization — `Init_Cart()`

Called once from `main()` before `ZX_Z80Reset()`:

1. Sets `BusOn`/`BusOff`/`DataMask`/`RamBase`/`RomLast`/pin constants.
2. Sets `handover_addr = 0xFFFF` (handover inactive).
3. Configures BUSREQ and /INT as open-drain outputs (idle HIGH).
4. Configures ROMCS (PB3) as push-pull HIGH (cart ROM selected).
5. Configures address, data, and control pins as inputs.
6. Clears EXTI pending flag, registers `RunCartWithRAM` as VTF fast ISR on
   EXTI15_10, enables the NVIC line.

---

## Files involved

| File | Role |
|---|---|
| [User/zx_bus.c](../User/zx_bus.c) | `RunCartWithRAM` ISR, all bus functions, ROMCS/NMI/reset control |
| [User/zx_bus.h](../User/zx_bus.h) | Public API and `ZX_Z80State` struct |
| [User/gpio.c](../User/gpio.c) | Early GPIO clock/AFIO enable and EXTI line config (called before `Init_Cart`) |
| [User/zx_image.h](../User/zx_image.h) | `g_zx_image[]` — compiled zxprog binary served as cart ROM |
| [zx_src/crt0.s](../zx_src/crt0.s) / [zxprog.c](../zx_src/zxprog.c) | Z80-side mailbox handlers (WCMD, RCMD, PGCMD, NMI wrapper) |

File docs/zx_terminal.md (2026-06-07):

# ZX Terminal — MPU-Rendered Screen and UI

This document explains the architecture of `zx_terminal.c`, what each
subsystem does, and how to use the public API.

---

## Overview

`zx_terminal` is the CH32-side UI layer that renders content onto the ZX
Spectrum screen from the cartridge MCU.  It does **not** run on the Z80 —
the CH32 builds a complete 6144-byte pixel buffer and a 768-byte attribute
buffer in internal SRAM, then pushes the data to ZX RAM (`0x4000–0x5AFF`)
via the NMI WCMD mailbox.  The Spectrum's ULA reads those buffers and
displays them on the screen without any cooperation from the Z80.

Three independent subsystems share the same pair of screen buffers:

| Subsystem | Purpose |
|---|---|
| **Virtual terminal** (`zxtty`) | Software 32×24 VT100-compatible text terminal rendered in the custom 4×7 font |
| **File browser** (`z80select` / `tapselect`) | Interactive full-screen file selector driven by ZX keyboard input |
| **Bridge text** (`zxmsg`) | Single-line status message written at a fixed cart RAM address and rendered by `zxprog` itself |

---

## Screen rendering pipeline

```
CH32 builds:        s_gfx_pixels[6144]   +   s_gfx_attrs[768]
                           │
              ZX_TermFlushBuffers()
                           │
              ┌────────────┴────────────────┐
              │ First call (s_prev_valid=0) │ Subsequent calls (diff mode)
              │ Full write: two chunked NMI │ ZX_BusWriteDiff: only changed
              │ WCMD calls (512 B/chunk)    │ regions (merge gap ≤ 16 B)
              └────────────────────────────┘
                           │
          ZX RAM 0x4000–0x57FF  (pixel data)
          ZX RAM 0x5800–0x5AFF  (attribute data)
                           │
                    ZX ULA displays
```

Differential writes (`ZX_BusWriteDiff`) skip unchanged bytes and merge runs
of unchanged bytes that are ≤ 16 bytes wide.  This keeps NMI traffic low
when only a small part of the screen changes (e.g. a cursor movement or a
single row update in the browser).

---

## Font

All text is rendered using a **4×7 pixel** proportional bitmap font stored
in `s_font4x7[]`.  Each character occupies one full 8×8 attribute cell
(one byte per row, upper 4 bits unused, lower 4 bits expanded 2× to fill
8 pixels).  In selector/browser mode a 1-pixel right-edge gutter is applied
to prevent adjacent characters from visually merging.

Supported characters: `0–9`, `A–Z`, `space`, `"  - . : / _`

Lower-case input is silently up-cased; unsupported characters are replaced
with a space.

---

## Attribute encoding

ZX Spectrum attribute bytes:

```
Bit 7   FLASH  (not used by the terminal)
Bit 6   BRIGHT
Bits 5-3  PAPER colour (0=black … 7=white)
Bits 2-0  INK colour   (0=black … 7=white)
```

Standard colour codes match ANSI SGR 30–37 (foreground) and 40–47
(background).  The default state is **black ink on white paper** (no bright).

---

## Virtual terminal (`zxtty`)

A 32-column × 24-row character terminal with cursor tracking and scroll-up.
Accepts a stream of bytes including:

| Input | Action |
|---|---|
| `\r`  | Carriage return (column → 0) |
| `\n`  | Newline (next row; scroll if at bottom) |
| `\b`  | Backspace (erase previous cell) |
| `\t`  | Tab (advance to next 4-column tab stop) |
| `ESC [` … | ANSI CSI sequence |

**Supported ANSI CSI sequences** (subset):

| Sequence | Action |
|---|---|
| `ESC [ n A` | Cursor up n rows |
| `ESC [ n B` | Cursor down n rows |
| `ESC [ n C` | Cursor right n columns |
| `ESC [ n D` | Cursor left n columns |
| `ESC [ row ; col H` | Set cursor position (1-based) |
| `ESC [ row ; col f` | Same as `H` |
| `ESC [ J` | Clear screen |
| `ESC [ K` | Clear to end of line |
| `ESC [ … m` | SGR — set colours / reset (see below) |

**SGR parameters understood**:

| Code | Effect |
|---|---|
| `0` or none | Reset (black ink, white paper, no bright) |
| `1` | Bold / bright on |
| `30`–`37` | Set foreground (ink) colour |
| `40`–`47` | Set background (paper) colour |

### Using the terminal from the UART command line

```
zxtty init               — clear screen and reset colours
zxtty hello world        — write "HELLO WORLD" at current cursor
zxtty \e[2JHELLO\n       — clear screen, write "HELLO", newline
zxtty \e[1;32mOK\e[0m    — bright green "OK", then reset
```

Escape sequences in the argument use C-style backslash notation:
`\n` = newline, `\r` = CR, `\t` = tab, `\e` = ESC (`0x1B`), `\\` = `\`.

> The terminal is purely output-only — there is no input path from the Z80
> keyboard to `zxtty`.  Use `z80select` or `tapselect` for interactive UIs.

---

## File browser (`z80select` / `tapselect`)

A full-screen interactive file browser rendered on the ZX screen.  The user
navigates with the ZX Spectrum keyboard; key events are read back to the CH32
via the **KEY mailbox** (`0x3028`/`0x3029`) polled by `ZX_KeyPoll()`.

### Browser layout (32×24)

```
Row 0   "RISKY SPECCY"
Row 1   Current path
Row 2   "Q/A MOVE  O/P PAGE"
Row 3   "ENTER LOAD/OPEN" or "ENTER QUEUE/OPEN" or "ENTER OPEN  0 BACK"
Row 4   (blank)
Rows 5-22  File list (18 entries per page)
Row 23  "N/M FILES" counter
```

Directories are shown as `[NAME]`; the selected entry is highlighted with
inverted colours and prefixed `>`.

### Keyboard controls

| Key | Action |
|-----|---|
| `Q` | Move selection up |
| `A` | Move selection down |
| `O` | Page up (−18) |
| `P` | Page down (+18) |
| `ENTER` | Open directory / load file / queue tape |
| `0` | Go back to parent directory |

### z80select flow

1. Browser scans the USB filesystem for `.z80`, `.tap`, and `.tzx` files.
2. Selecting a `.z80` file shows a **snapshot info page** (version, PC, SP,
   hardware mode, compression, file size).  Pressing `ENTER` confirms load;
   pressing `0` cancels.
3. After confirmation `Z80_LoadAndRun()` is called directly.  On success the
   game is running and `ZX_TerminalCommandZ80Select` does not return to the
   browser.  On failure an error screen is shown and the browser resets.
4. Selecting a `.tap` or `.tzx` file loads it into the tape player buffer,
   shows a **TAPE READY** screen, then releases ROMCS and resets the Z80 to
   BASIC.  The pending path is stored; the caller checks
   `ZX_TerminalPendingTapSelection()` and can start playback via a button
   press.

### tapselect flow

Like `z80select` but only `.tap` and `.tzx` files are listed.  Selecting a
file loads it into the tape player buffer and resets the Z80 to BASIC.
The pending path is stored for the caller to retrieve via
`ZX_TerminalPendingTapSelection()`.

### Pending selections (used by `zx_monitor`)

Both browsers can end with a pending selection that the caller must act on
**after** the function returns:

```c
ZX_TerminalCommandZ80Select("/");
const char *path = ZX_TerminalPendingZ80Selection();
if (path && path[0]) {
    Z80_LoadAndRun(path);
    ZX_TerminalClearPendingZ80Selection();
}

ZX_TerminalCommandTapSelect("/");
const char *tap = ZX_TerminalPendingTapSelection();
if (tap && tap[0]) {
    /* TAP_Player_Start() triggered externally (e.g. button press) */
    ZX_TerminalClearPendingTapSelection();
}
```

> `zx_monitor.c` uses exactly this pattern for the `z80select`, `tapselect`,
> and auto-start flows.

---

## RAM viewer (`zxview`)

Sends a config to `zxprog` via the VIEW mailbox (`0x302A`–`0x302D`) so the
Z80-side code displays a hex dump of ZX RAM on the border/screen.

```c
ZX_TerminalCommandView(0x4000u, 16u);  /* dump 16 bytes at 0x4000 */
ZX_TerminalCommandViewOff();           /* disable viewer */
```

The VIEW mailbox:

```
0x302A  VIEW_SEQ    — incremented to trigger update
0x302B  VIEW_ADDR_LO — low byte of start address
0x302C  VIEW_ADDR_HI — high byte of start address
0x302D  VIEW_LEN    — byte count (max 16)
```

> **Shared with PGCMD:** `0x302A–0x302C` is also used by the **PGCMD**
> mailbox during snapshot loading. The two are time-sequenced — the CH32
> only drives VIEW_SEQ after ROMCS has been released, so they never
> collide. See the full cart RAM map in
> [z80_launch_mechanism.md — Cart RAM layout](z80_launch_mechanism.md#cart-ram-layout).

---

## Bridge text (`zxmsg`)

Writes up to 40 characters to the **BRIDGE mailbox** (`0x3000`–`0x3029`):

```c
ZX_TerminalCommandBridgeText("hello world");
```

The BRIDGE mailbox:

```
0x3000  BRIDGE_SEQ  — incremented to signal new text
0x3001  BRIDGE_LEN  — byte count
0x3002  BRIDGE_TEXT[40] — text payload
```

`zxprog` reads `BRIDGE_SEQ` each NMI cycle; when it changes it copies
`BRIDGE_TEXT[BRIDGE_LEN]` to a fixed screen position and redraws it.

`ZX_TerminalMarkBridgeDirty()` increments `BRIDGE_SEQ` and writes it to cart
RAM without changing the text — used to force a redraw after the screen has
been overwritten by another subsystem.

---

## Initialization

```c
ZX_TerminalInit();   /* call once, before any other terminal function */
```

Resets all internal state: cursor position, colours, ESC parser, diff
buffers, pending selections.  Called by `ZX_Monitor_Init()` at startup.

---

## Draw suspension

While the browser or terminal is actively writing to ZX RAM, it suspends the
`zxprog` main loop's own screen-draw routine to prevent races:

```c
ZX_CartDrawSuspend();   /* set CTRL_FLAGS bit 0; zxprog stops drawing */
/* ... write screen ... */
ZX_CartDrawResume();    /* clear bit 0; zxprog resumes */
ZX_TerminalMarkBridgeDirty();  /* force bridge redraw after resume */
```

This is handled automatically inside `ZX_TerminalCommandZ80Select` and
`ZX_TerminalCommandTapSelect`.

---

## Public API summary

| Function | Description |
|---|---|
| `ZX_TerminalInit()` | Reset all state; call once at startup |
| `ZX_TerminalCommandTermInit()` | Clear virtual terminal and reset colours |
| `ZX_TerminalCommandTermWrite(firstToken)` | Write text (with `\n\r\t\e` escapes) to the virtual terminal |
| `ZX_TerminalCommandView(address, length)` | Enable ZX RAM hex viewer |
| `ZX_TerminalCommandViewOff()` | Disable ZX RAM hex viewer |
| `ZX_TerminalCommandBridgeText(firstToken)` | Send a text message to `zxprog` bridge display |
| `ZX_TerminalMarkBridgeDirty()` | Force bridge text redraw |
| `ZX_TerminalCommandZ80Select(path)` | Open interactive .z80/.tap/.tzx browser |
| `ZX_TerminalCommandTapSelect(path)` | Open interactive .tap/.tzx browser |
| `ZX_TerminalPendingZ80Selection()` | Returns pending .z80 path after `Z80Select` |
| `ZX_TerminalClearPendingZ80Selection()` | Clear pending path |
| `ZX_TerminalPendingTapSelection()` | Returns pending tape path after `TapSelect` |
| `ZX_TerminalClearPendingTapSelection()` | Clear pending path |

---

## Files involved

| File | Role |
|---|---|
| [User/zx_terminal.c](../User/zx_terminal.c) | Full implementation |
| [User/zx_terminal.h](../User/zx_terminal.h) | Public API declarations |
| [User/zx_monitor.c](../User/zx_monitor.c) | Caller: exposes `zxtty`, `zxmsg`, `zxview`, `z80select`, `tapselect` as UART commands |
| [User/zx_bus.c](../User/zx_bus.c) | `ZX_BusWriteBlock`, `ZX_CartRamWriteBlock`, `ZX_KeyPoll` |
| [User/tape_player.c](../User/tape_player.c) | `TAP_Player_Load`, `TAP_Player_Start` called from browser |
| [User/z80_loader.c](../User/z80_loader.c) | `Z80_LoadAndRun`, `Z80_GetFileInfo` called from browser |

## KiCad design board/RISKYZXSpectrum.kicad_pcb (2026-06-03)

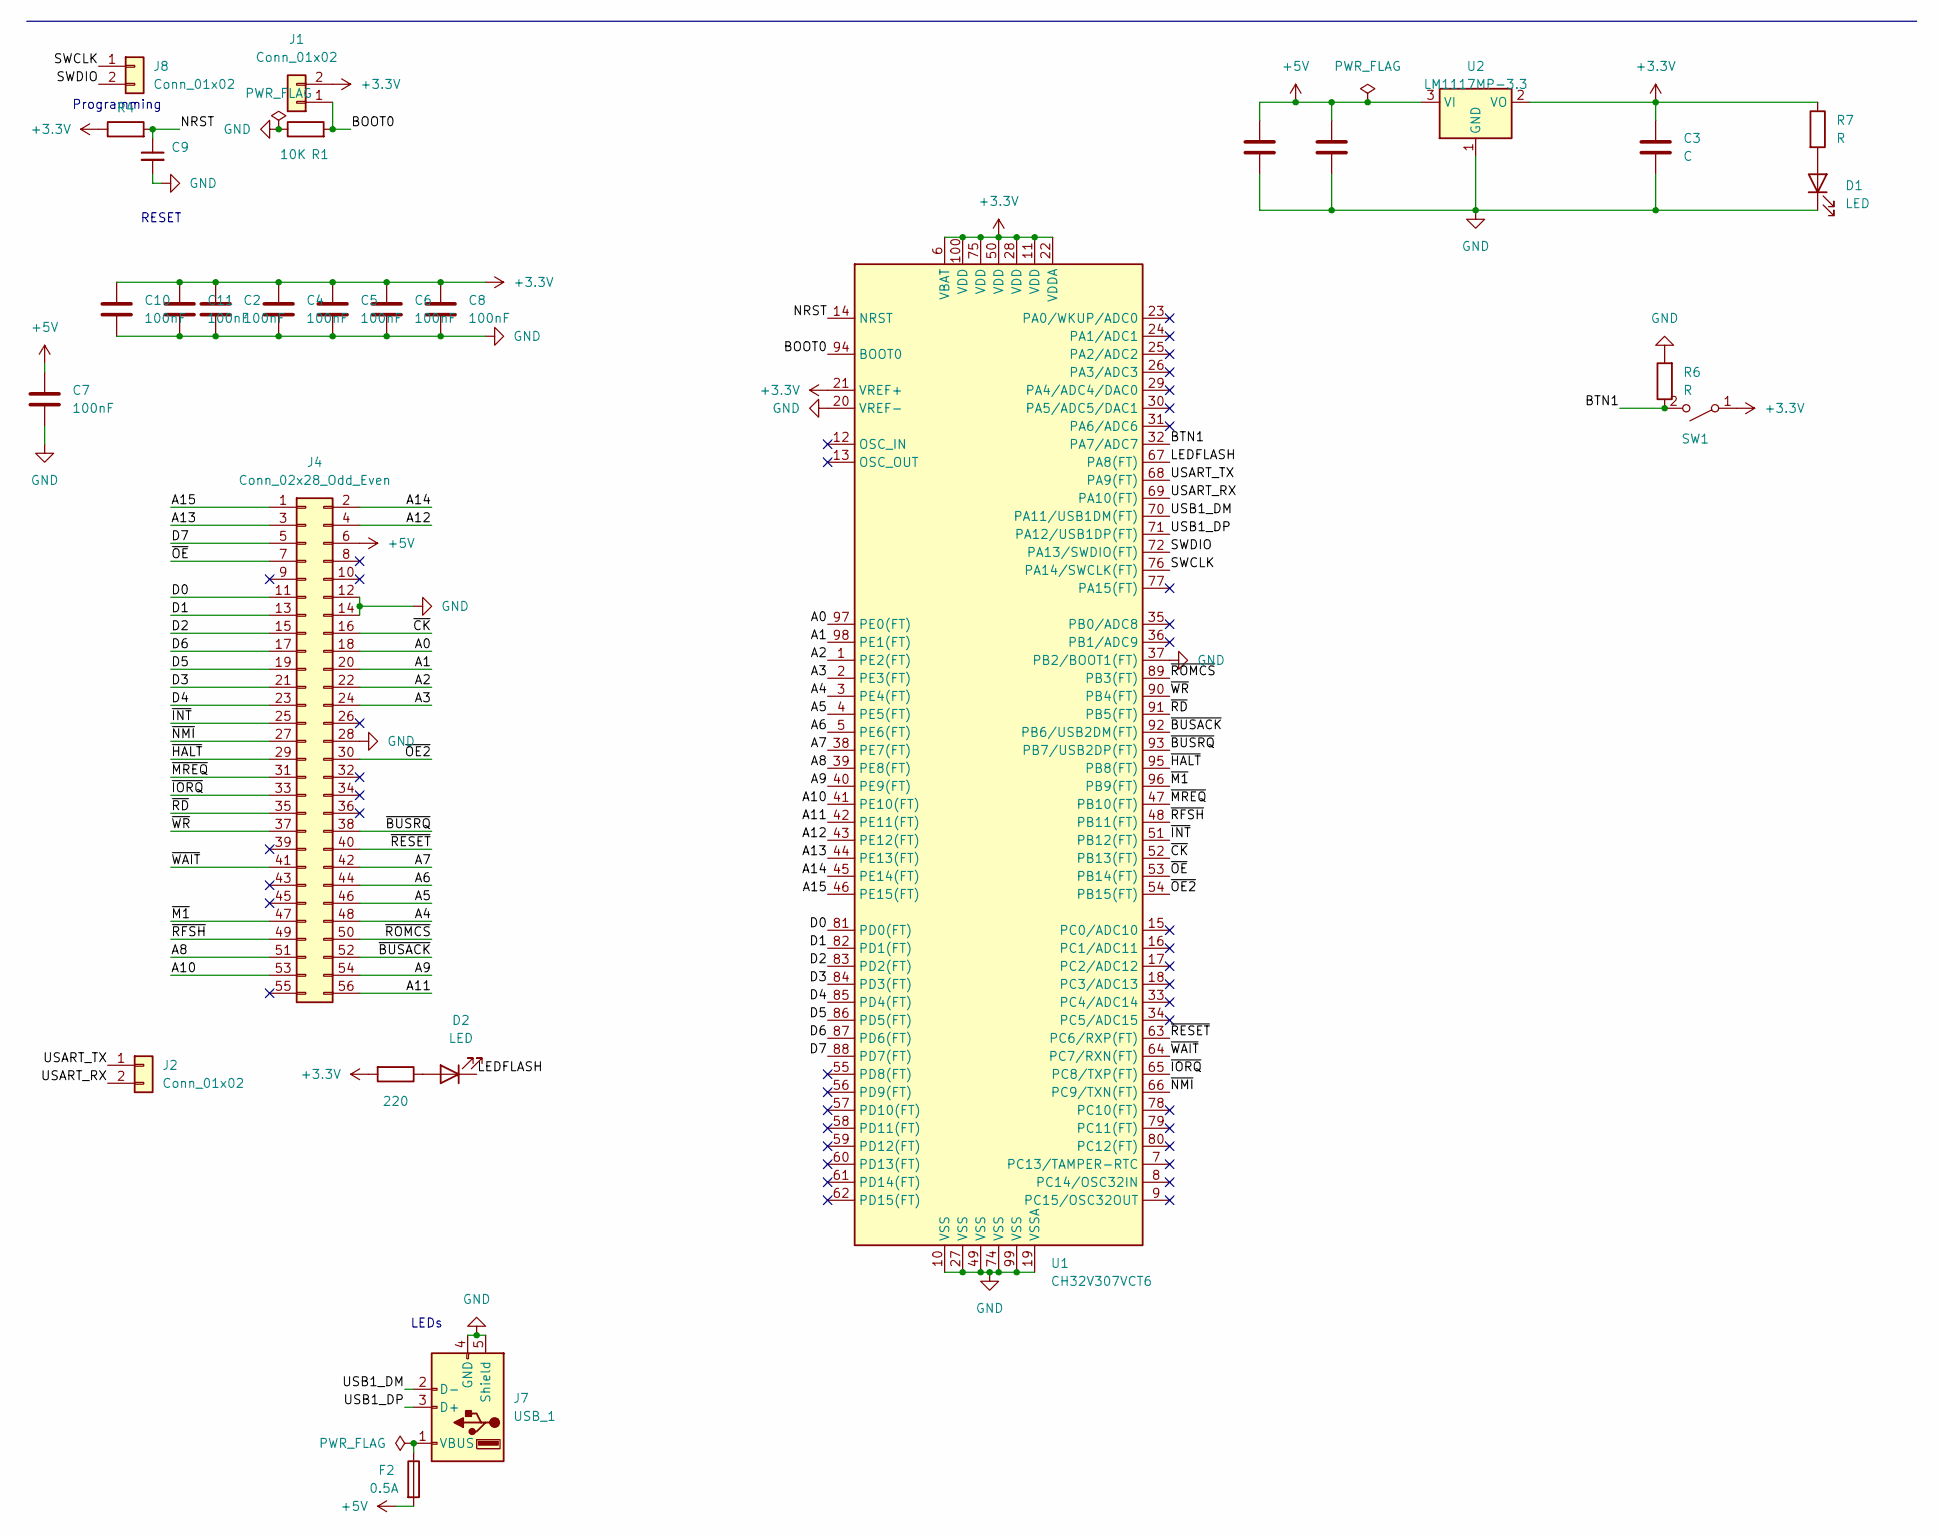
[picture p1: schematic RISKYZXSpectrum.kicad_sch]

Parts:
C1, C3, C12: C; C_0603_1608Metric_Pad1.08x0.95mm_HandSolder
C2, C4, C5, C6, C8, C10, C11: 100nF; C_0603_1608Metric_Pad1.08x0.95mm_HandSolder
C7: 100nF; C_1206_3216Metric_Pad1.33x1.80mm_HandSolder
C9: 100nF; C_0603_1608Metric_Pad1.08x0.95mm_HandSolder; LCSC C14663
D1, D2: LED; LED_0805_2012Metric_Pad1.15x1.40mm_HandSolder
F2: 0.5A; Fuse_1206_3216Metric_Pad1.42x1.75mm_HandSolder
J1, J2, J8: Conn_01x02; PinHeader_1x02_P2.54mm_Vertical
J4: Conn_02x28_Odd_Even; EdgeConnector_254x508x2x28_OddEven
J7: USB_1; USB_A_Connfly_DS1095
R1, R4: 10K; R_0603_1608Metric_Pad0.98x0.95mm_HandSolder
R5: 220; R_0603_1608Metric_Pad0.98x0.95mm_HandSolder
R6, R7: R; R_0603_1608Metric_Pad0.98x0.95mm_HandSolder
SW1: SW_SPST; SW_PUSH_6mm
U1: CH32V307VCT6; LQFP-100_14x14mm_P0.5mm
U2: LM1117MP-3.3; SOT-223-3_TabPin2

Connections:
+3.3V: C2.1, C3.1, C4.1, C5.1, C6.1, C8.1, C10.1, C11.1, J1.2, R4.1, R5.2, R7.1, SW1.1 (A), U1.6 (VBAT), U1.11 (VDD), U1.21 (VREF+), U1.22 (VDDA), U1.28 (VDD), U1.50 (VDD), U1.75 (VDD), U1.100 (VDD), U2.2 (VO)
+5V: C1.1, C7.1, C12.1, F2.2, J4.6, U2.3 (VI)
/A0: J4.18, U1.97 (PE0(FT))
/A1: J4.20, U1.98 (PE1(FT))
/A2: J4.22, U1.1 (PE2(FT))
/A3: J4.24, U1.2 (PE3(FT))
/A4: J4.48, U1.3 (PE4(FT))
/A5: J4.46, U1.4 (PE5(FT))
/A6: J4.44, U1.5 (PE6(FT))
/A7: J4.42, U1.38 (PE7(FT))
/A8: J4.51, U1.39 (PE8(FT))
/A9: J4.54, U1.40 (PE9(FT))
/A10: J4.53, U1.41 (PE10(FT))
/A11: J4.56, U1.42 (PE11(FT))
/A12: J4.4, U1.43 (PE12(FT))
/A13: J4.3, U1.44 (PE13(FT))
/A14: J4.2, U1.45 (PE14(FT))
/A15: J4.1, U1.46 (PE15(FT))
/BOOT0: J1.1, R1.2, U1.94 (BOOT0)
/BTN1: R6.1, SW1.2 (B), U1.32 (PA7/ADC7)
/D0: J4.11, U1.81 (PD0(FT))
/D1: J4.13, U1.82 (PD1(FT))
/D2: J4.15, U1.83 (PD2(FT))
/D3: J4.21, U1.84 (PD3(FT))
/D4: J4.23, U1.85 (PD4(FT))
/D5: J4.19, U1.86 (PD5(FT))
/D6: J4.17, U1.87 (PD6(FT))
/D7: J4.5, U1.88 (PD7(FT))
/LEDFLASH: D2.1 (K), U1.67 (PA8(FT))
/NRST: C9.1, R4.2, U1.14 (NRST)
/SWCLK: J8.1, U1.76 (PA14/SWCLK(FT))
/SWDIO: J8.2, U1.72 (PA13/SWDIO(FT))
/USART_RX: J2.2, U1.69 (PA10(FT))
/USART_TX: J2.1, U1.68 (PA9(FT))
/USB1_DM: J7.2 (D-_2), U1.70 (PA11/USB1DM(FT))
/USB1_DP: J7.3 (D+_3), U1.71 (PA12/USB1DP(FT))
/~BUSACK: J4.52, U1.92 (PB6/USB2DM(FT))
/~BUSRQ: J4.38, U1.93 (PB7/USB2DP(FT))
/~CK: J4.16, U1.52 (PB13(FT))
/~HALT: J4.29, U1.95 (PB8(FT))
/~INT: J4.25, U1.51 (PB12(FT))
/~IORQ: J4.33, U1.65 (PC8/TXP(FT))
/~M1: J4.47, U1.96 (PB9(FT))
/~MREQ: J4.31, U1.47 (PB10(FT))
/~NMI: J4.27, U1.66 (PC9/TXN(FT))
/~OE2: J4.30, U1.54 (PB15(FT))
/~OE: J4.7, U1.53 (PB14(FT))
/~RD: J4.35, U1.91 (PB5(FT))
/~RESET: J4.40, U1.63 (PC6/RXP(FT))
/~RFSH: J4.49, U1.48 (PB11(FT))
/~ROMCS: J4.50, U1.89 (PB3(FT))
/~WAIT: J4.41, U1.64 (PC7/RXN(FT))
/~WR: J4.37, U1.90 (PB4(FT))
GND: C1.2, C2.2, C3.2, C4.2, C5.2, C6.2, C7.2, C8.2, C9.2, C10.2, C11.2, C12.2, D1.1 (K), J4.12, J4.14, J4.28, J7.4 (GND_4), J7.5 (Shield), J7.SH (Shield_5), R1.1, R6.2, U1.10 (VSS), U1.19 (VSSA), U1.20 (VREF-), U1.27 (VSS), U1.37 (PB2/BOOT1(FT)), U1.49 (VSS), U1.74 (VSS), U1.99 (VSS), U2.1 (GND)
unnamed: D1.2 (A), R7.2
unnamed: D2.2 (A), R5.1
unnamed: F2.1, J7.1 (VBUS_1)

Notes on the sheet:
RESET
Programming
LEDs

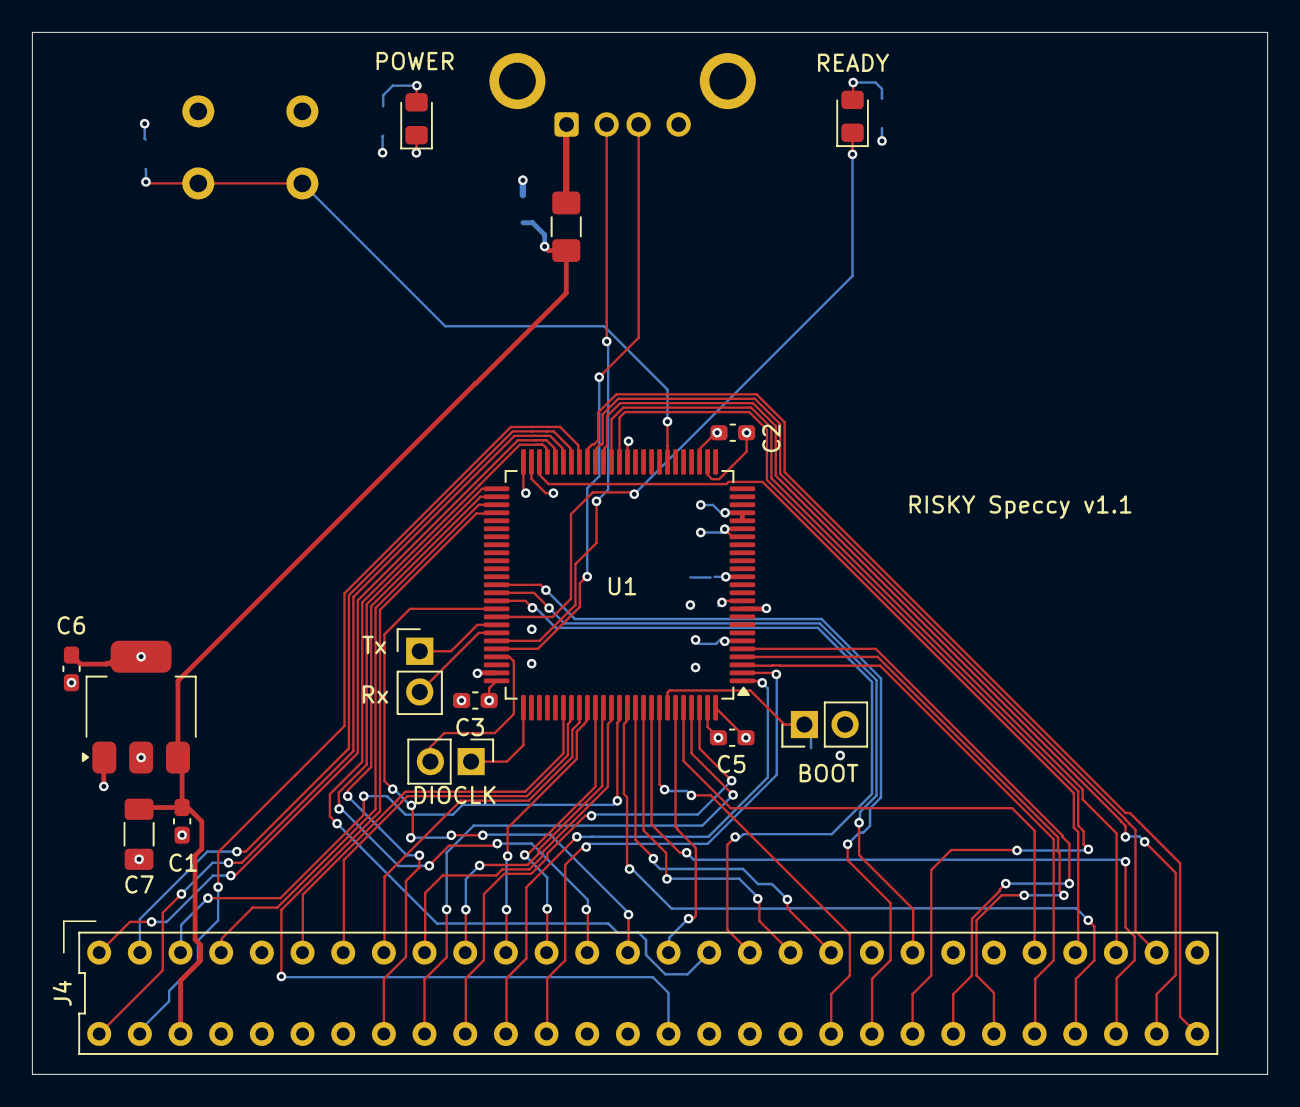
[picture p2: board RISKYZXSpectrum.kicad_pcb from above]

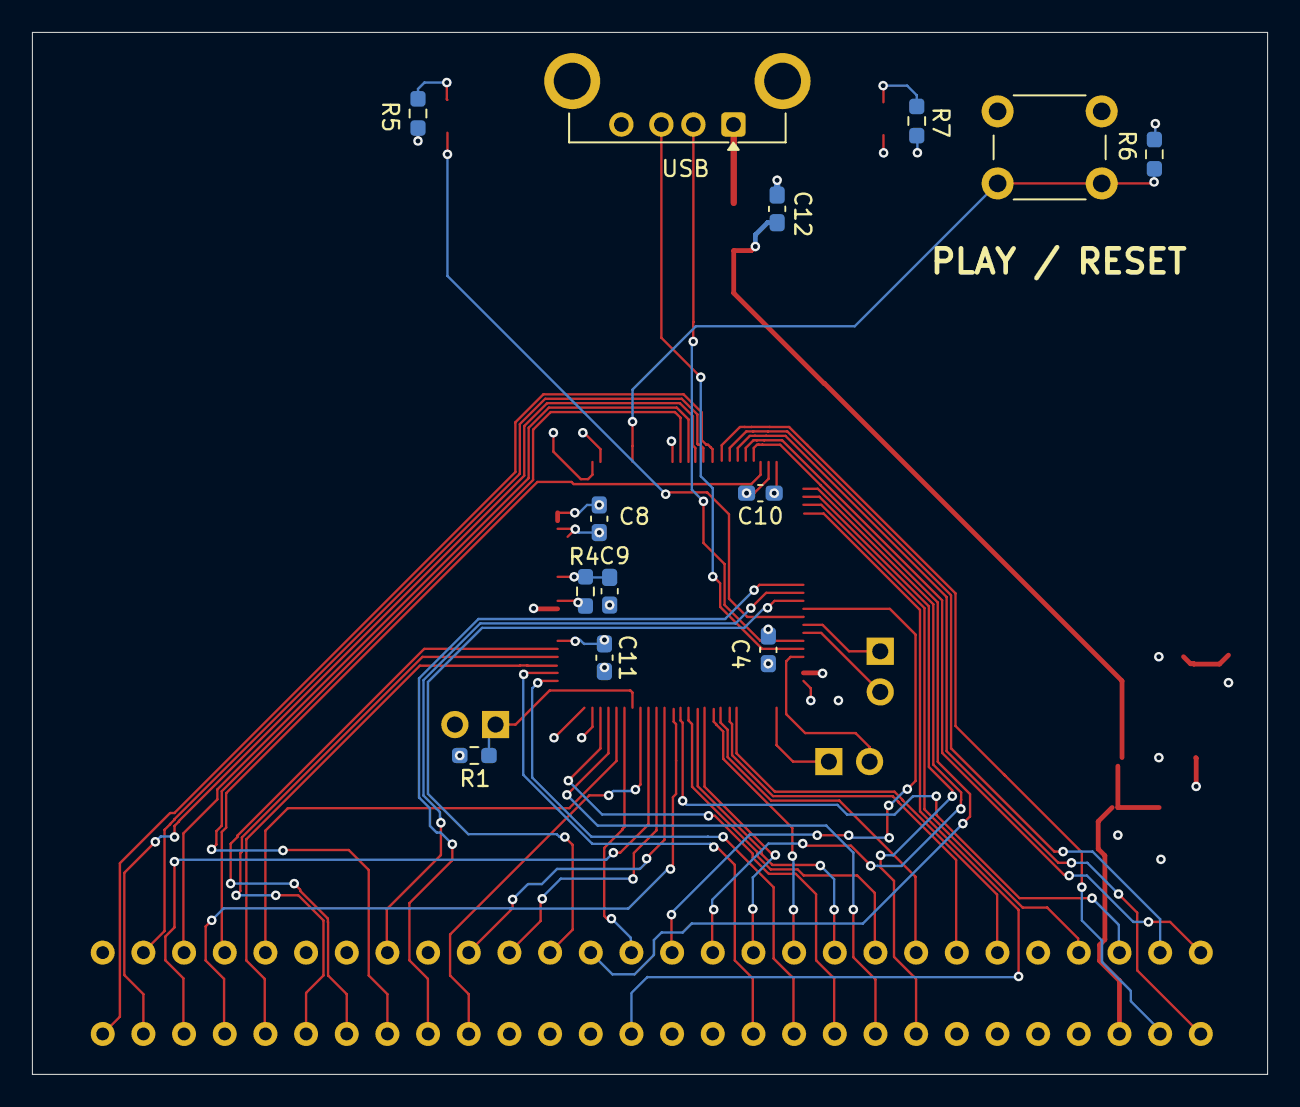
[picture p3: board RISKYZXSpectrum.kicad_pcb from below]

Board: 4 copper layers, 77.1 x 65.1 mm, 28 parts (13 on the bottom side), 57 nets.

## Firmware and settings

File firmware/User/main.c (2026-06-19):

#include "debug.h"
#include "gpio.h"
#include "tape_player.h"
#include "usb_disk.h"
#include "zx_bus.h"
#include "zx_image.h"
#include "zx_terminal.h"
#include "reset_button.h"
#include "ff.h"

#include <stdio.h>

static FATFS s_fatfs;

int main (void) {
    NVIC_PriorityGroupConfig (NVIC_PriorityGroup_2);
    SystemCoreClockUpdate();
    Delay_Init();
    USART_Printf_Init (115200);
    GPIO_Config();
    USB_Initialization();
    Init_Cart();

    GPIO_InitTypeDef gpio = {0};
    /* Re-drive ROMCS as push-pull HIGH (cart ROM selected). */
    gpio.GPIO_Pin = GPIO_Pin_14;
    gpio.GPIO_Mode = GPIO_Mode_Out_PP;
    gpio.GPIO_Speed = GPIO_Speed_50MHz;
    GPIO_Init (GPIOB, &gpio);
    GPIO_SetBits (GPIOB, GPIO_Pin_14);
        /* Re-drive ROMCS as push-pull HIGH (cart ROM selected). */
    gpio.GPIO_Pin = GPIO_Pin_15;
    gpio.GPIO_Mode = GPIO_Mode_Out_PP;
    gpio.GPIO_Speed = GPIO_Speed_50MHz;
    GPIO_Init (GPIOB, &gpio);
    GPIO_SetBits (GPIOB, GPIO_Pin_15);

    ZX_Z80Reset();

    /* Mount USB MSC filesystem (lazy: actual init runs on first f_open). */
    {
        FRESULT fr = f_mount (&s_fatfs, "", 0);
        if (fr != FR_OK) {
            printf ("WARN: f_mount failed (fr=%d) — USB drive features disabled\r\n",
                    (int)fr);
        }
    }
    printf ("Hello from RISKY ZX Spectrum firmware!\n");

    setvbuf (stdout, NULL, _IONBF, 0);
    ZX_TerminalInit();

    /* Wait until ZX bus is accessible, then launch the file browser loop. */
    {
        uint8_t probe = 0u;
        while (!ZX_BusReadBlock (0x0000u, &probe, 1u)) {
            Handle_ResetButtonPA7();
        }
    }

     /* Show "Insert USB Drive" prompt on the ZX display and wait until the user
         inserts a drive and presses Enter on the ZX keyboard. */
     ZX_TerminalWaitUsbDriveReady();

    for (;;) {
        /* USB-state watchdog.  The file browser and TAP player are long-
         * running blocking functions that previously never re-tested the
         * USB host stack, so an unplug while they were running left the
         * launcher in a wedged state.  Each iteration of the main loop
         * asks the terminal layer whether the drive is still attached and
         * jumps back to the insert-USB prompt if it isn't. */
        ZX_TerminalPollUsb ();
        if (ZX_TerminalUsbLost ()) {
            printf ("main: USB drive lost, re-prompting\r\n");
            ZX_TerminalClearPendingZ80Selection ();
            ZX_TerminalClearPendingTapSelection ();
            ZX_TerminalClearUsbLost ();
            goto recheck_usb;
        }

        /* Open file browser (blocks until the user selects a file or cancels). */
        if (ZX_TerminalCommandZ80Select (NULL)) {
            /* Z80 game launched inside the terminal; spin here forever.
               Only a long-press hardware reset makes sense at this point.
               Also poll for an external ZX hardware reset: if the user
               presses the Spectrum's reset button (wired to PC6), zxprog
               re-runs in isolation with the cart ISR re-armed by the
               Spectrum's ROM-wins signalling — but the terminal/browser/
               tap state in CH32 RAM (s_prev_valid, s_selector_font_mode,
               pending tap selections, terminal char/attr model, etc.) is
               now stale and trying to surgically re-engage the cart from
               here leaves the launcher either invisible or showing a
               stray yellow/green border flash.  Issue a full NVIC reset
               so main() runs from the top: every peripheral is
               reinitialised, the cart state machine starts clean, FATFS
               is re-mounted, the file browser is reopened. */
            for (;;) {
                if (ZX_HandleExternalResetIfAny ()) {
                    printf ("ZX hardware reset detected — full CH32 reset\r\n");
                    NVIC_SystemReset();
                }
                Handle_ResetButtonPA7();
            }
        }

        /* .tap/.tzx selected: z80select already switched the ZX to BASIC and
           queued the path.  Poll the button until the user short-presses to
           start playback.  Do NOT clear pending here — the button handler
           needs it to know which file to load. */
        if ((ZX_TerminalPendingTapSelection() != NULL) &&
            (ZX_TerminalPendingTapSelection()[0] != '\0')) {

            /* Wait for a short press that actually starts the tape.
               Also bail out on a ZX hardware reset — same reasoning as
               the z80-spin path above: stale browser/tap/terminal state
               in CH32 RAM makes a partial recovery unreliable, so we do
               a full NVIC reset to restart cleanly from main(). */
            while (!TAP_Player_IsRunning()) {
                if (ZX_HandleExternalResetIfAny ()) {
                    printf ("ZX hardware reset detected — full CH32 reset\r\n");
                    NVIC_SystemReset();
                }
                Handle_ResetButtonPA7();
            }

            /* Tape is running: keep polling (allows long-press reset and
               external ZX reset).  Same full-reset recovery model. */
            while (TAP_Player_IsRunning()) {
                if (ZX_HandleExternalResetIfAny ()) {
                    printf ("ZX hardware reset detected — full CH32 reset\r\n");
                    NVIC_SystemReset();
                }
                Handle_ResetButtonPA7();
            }

            /* Tape finished: the Z80 is now running the loaded program.
               Spin here like the z80 snapshot path — ZX hardware reset
               triggers a full CH32 reset to bring the launcher back. */
            ZX_TerminalClearPendingTapSelection();
            for (;;) {
                if (ZX_HandleExternalResetIfAny ()) {
                    printf ("ZX hardware reset detected — full CH32 reset\r\n");
                    NVIC_SystemReset();
                }
                Handle_ResetButtonPA7();
            }
        }
        /* Nothing selected (user cancelled/escaped): loop and reopen browser. */
        continue;
recheck_usb:
        /* Drive was unplugged: drop any in-flight selections, reset the
         * host stack so the next attach is observed cleanly, and re-run
         * the insert-USB prompt.  Loop back to the top of main(). */
        ClearUSB();
        USB_Initialization();
        ZX_TerminalWaitUsbDriveReady();
        continue;
    }
}

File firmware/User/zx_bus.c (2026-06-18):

#include "zx_bus.h"
#include "zx_image.h"


// GPIOE Pins    0 - 16      Address
// GPIOD Pins    0 - 8       Data

// GPIOB Pin     3           ROMCS  0x0008
// GPIOB Pin     4           WR     0x0010
// GPIOB Pin     5           RD     0x0020

// GPIOB Pin     6           BUSACK 0x0040
// GPIOB Pin     7           BUSREQ 0x0080
// GPIOB Pin     8           HALT   0x0100

// GPIOB Pin     9           M1    0x0200
// GPIOB Pin     10          MREQ  0x0400
// GPIOB Pin     11          RESH  0x0800
// GPIOB Pin     12          INT
// GPIOB Pin     13          CK

// GPIOC Pin     6           RESET 0x0040
// GPIOC Pin     7           WAIT  0x0080
// GPIOC Pin     8           IORQ  0x0100
// GPIOC Pin     9           BDIR  0x0200

#pragma GCC push_options
#pragma GCC optimize("Ofast")

#define ZX_ROM_LAST_ADDRESS 0x3FFFu

#define ZX_PIN_WR      GPIO_Pin_4
#define ZX_PIN_RD      GPIO_Pin_5
#define ZX_PIN_BUSACK  GPIO_Pin_6
#define ZX_PIN_BUSREQ  GPIO_Pin_7
#define ZX_PIN_MREQ    GPIO_Pin_10
#define ZX_PIN_INT     GPIO_Pin_12
#define ZX_PIN_CK_INV  GPIO_Pin_13

#define ZX_CTRL_MASK   (ZX_PIN_WR | ZX_PIN_RD | ZX_PIN_MREQ)

#define ZX_BUS_TIMEOUT        120000u

#define ZX_KEY_SEQ_ADDR       0x3028u
#define ZX_KEY_CODE_ADDR      0x3029u

/* NMI mailbox protocol (shared with zxprog) */
#define ZX_NMI_WCMD_SEQ_ADDR    0x302Eu
#define ZX_NMI_WCMD_DONE_ADDR   0x302Fu
#define ZX_NMI_WCMD_DST_LO_ADDR 0x3030u
#define ZX_NMI_WCMD_DST_HI_ADDR 0x3031u
#define ZX_NMI_WCMD_LEN_LO_ADDR 0x3032u
#define ZX_NMI_WCMD_LEN_HI_ADDR 0x3033u
#define ZX_NMI_WCMD_DATA_ADDR   0x3034u
#define ZX_NMI_WCMD_CHUNK       0x0200u

#define ZX_NMI_RCMD_SEQ_ADDR    0x3F20u
#define ZX_NMI_RCMD_DONE_ADDR   0x3F21u
#define ZX_NMI_RCMD_SRC_LO_ADDR 0x3F22u
#define ZX_NMI_RCMD_SRC_HI_ADDR 0x3F23u
#define ZX_NMI_RCMD_LEN_ADDR    0x3F24u
#define ZX_NMI_RCMD_BUF_ADDR    0x3F40u
#define ZX_NMI_RCMD_CHUNK       64u

#define ZX_NMI_TIMEOUT_MS       200u

struct ZXCartState {
    uint32_t BusOn;
    uint32_t BusOff;
    uint32_t DataMask;
    uint16_t RamBase;
    uint16_t RomLast;
    uint16_t PinRD;
    uint16_t PinWR;
    uint16_t PinMREQ;
    uint32_t IRQLine;
    /* When handover_addr != 0xFFFF, the cart ISR will tristate ROMCS and
       disable itself immediately after serving a read from this address.
       Set to 0x3FF5 (JP pc_hi of the launcher tail) before triggering
       _zx_launcher so the handover fires exactly when the Z80 jumps from
       cart space into game space. */
    volatile uint16_t handover_addr;
    /* ROM image served on reads from addresses [0 .. RamBase-1].
       Defaults to the embedded zxprog launcher (g_zx_image, 12 K).
       Repointed to a 16 K buffer when an Interface 2 cartridge ROM is loaded
       (see ZX_BecomeInterface2).  Read-only as far as the ISR is concerned. */
    const uint8_t *rom_image;
    volatile uint8_t ram[0x1000];
};

static struct ZXCartState s_state;
static struct ZXCartState *state_pointer;
static uint8_t s_key_last_seq = 0u;
static uint8_t s_nmi_wcmd_seq = 0u;
static uint8_t s_nmi_rcmd_seq = 0u;

/* Set to 1 when the cart has been released to the ZX (ROMCS tristated, ISR
 * disabled) — after a successful ZX_LaunchZ80 handover or an explicit
 * ZX_RomcsRelease().  Cleared when the cart re-asserts control via
 * ZX_RomcsAssert() or ZX_BecomeInterface2().  Used by
 * ZX_HandleExternalResetIfAny() to decide whether a PC6 falling edge is
 * meaningful (the user pressed the ZX hardware reset button while we were
 * spun out). */
static uint8_t s_cart_released = 0u;

static void ZX_DataBusInput (void) {
    GPIOD->CFGLR = 0x44444444;
}

static void ZX_AddrBusInput (void) {
    GPIOE->CFGLR = 0x44444444;
    GPIOE->CFGHR = 0x44444444;
}

static void ZX_CtrlLinesInput (void) {
    GPIO_InitTypeDef gpio = {0};
    gpio.GPIO_Pin = ZX_CTRL_MASK;
    gpio.GPIO_Mode = GPIO_Mode_IN_FLOATING;
    GPIO_Init (GPIOB, &gpio);
}


static int ZX_WaitClockToggle (uint32_t timeout) {
    uint16_t start_level = GPIOB->INDR & ZX_PIN_CK_INV;

    while (timeout-- > 0u) {
        if ((GPIOB->INDR & ZX_PIN_CK_INV) != start_level) {
            return 1;
        }
    }

    return 0;
}


static int ZX_NmiWriteBlockInternal (uint16_t address, const uint8_t *buffer, uint16_t length, uint32_t timeout_ms) {
    uint16_t offset = 0u;

    if ((buffer == NULL) && (length != 0u)) {
        return 0;
    }
    if (state_pointer == NULL) {
        return 0;
    }

    while (offset < length) {
        uint16_t chunk = (uint16_t)(length - offset);
        uint16_t dst = (uint16_t)(address + offset);
        uint8_t seq;
        uint8_t done;
        uint32_t waited;
        uint16_t i;

        if (chunk > ZX_NMI_WCMD_CHUNK) {
            chunk = ZX_NMI_WCMD_CHUNK;
        }

        ++s_nmi_wcmd_seq;
        seq = s_nmi_wcmd_seq;

        for (i = 0u; i < chunk; ++i) {
            state_pointer->ram[(ZX_NMI_WCMD_DATA_ADDR - 0x3000u) + i] = buffer[offset + i];
        }

        state_pointer->ram[ZX_NMI_WCMD_DST_LO_ADDR - 0x3000u] = (uint8_t)(dst & 0x00FFu);
        state_pointer->ram[ZX_NMI_WCMD_DST_HI_ADDR - 0x3000u] = (uint8_t)(dst >> 8);
        state_pointer->ram[ZX_NMI_WCMD_LEN_LO_ADDR - 0x3000u] = (uint8_t)(chunk & 0x00FFu);
        state_pointer->ram[ZX_NMI_WCMD_LEN_HI_ADDR - 0x3000u] = (uint8_t)(chunk >> 8);
        __asm volatile ("" ::: "memory");
        state_pointer->ram[ZX_NMI_WCMD_SEQ_ADDR - 0x3000u] = seq;

        ZX_TriggerNMI();

        waited = 0u;
        do {
            done = state_pointer->ram[ZX_NMI_WCMD_DONE_ADDR - 0x3000u];
            if (done == seq) {
                break;
            }
            Delay_Us (500u);
            waited += 1u;
        } while (waited < timeout_ms * 2u);

        if (done != seq) {
            return 0;
        }

        offset = (uint16_t)(offset + chunk);
    }

    return 1;
}
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

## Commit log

2026-03-22 Initial PCB
    [RISKYZXSpectrum.kicad_pcb, RISKYZXSpectrum.kicad_sch]
2026-04-19 Initial working device as EPROM with random game
    [RISKYZXSpectrum-B_Cu.gbr, RISKYZXSpectrum-B_Mask.gbr, RISKYZXSpectrum-B_Paste.gbr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]
2026-05-01 Reset at PA7 and clear RAM and screen
    [main.c, zx_bus.c]
2026-05-01 ZX Spectrum reset after init
    [main.c]
2026-05-07 Remove firmware version from README
    Removed current firmware version information from README.
2026-05-07 Refactor firmware structure and remove unused components
    - Removed `utils.c` and `utils.h` as they were no longer needed.
    - Eliminated `zx_monitor.c` and `zx_monitor.h`, integrating their functionality into the terminal loader.
    - Updated `diskio.c` to remove unused `utils.h` and `CircularBuffer` reference.
    - Modified `main.c` to initialize terminal and handle Z80 selection directly.
    - Enhanced `tape_player.c` and `tape_player.h` documentation to reflect changes in command flow.
    - Added version display in terminal outputs.
    - Introduced new binary files for ZX programming.
    [main.c, tape_player.c, utils.c]
2026-05-08 Bugfix - reset after loading tape
    [main.c]
2026-05-08 z80 reset bug fix
    [main.c]
2026-05-09 PCB udpate
    [RISKYZXSpectrum-B_Cu.gbr, RISKYZXSpectrum-B_Mask.gbr, RISKYZXSpectrum-B_Paste.gbr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]
2026-05-10 tidy up hitory kiCad
2026-05-10 Stop tracking board/.history
2026-06-03 Update PCB job file and firmware for ROMCS handling - Updated the PCB job file version from 10.0.1 to 10.0.3 and adjusted the creation date. - Modified the RunCartWithRAM function to configure GPIO s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
    [RISKYZXSpectrum-B_Cu.gbr, RISKYZXSpectrum-B_Mask.gbr, RISKYZXSpectrum-B_Paste.gbr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]
2026-06-07 Refactor bootloader and documentation for clarity and functionality improvements
    - Adjusted LED blink count in main bootloader loop for better user feedback.
    - Enhanced Makefile with new split configuration commands and documentation.
    - Updated README with clearer instructions on build outputs and flashing options.
    - Improved bootloader documentation to clarify flash limits and application linker script.
    - Added detailed bus architecture diagram and explanations in zx_bus.md.
    - Clarified shared mailbox usage in zx_terminal.md and z80_launch_mechanism.md.
2026-06-18 ZX Spectrum Reset fix
    [main.c, zx_bus.c]
2026-06-19 USB handling fixes and READY LED support
    [gpio.c, main.c]
2026-06-19 ZX Spectrum Reset bugfix. Now cart performs full internal reset at zx spectrum reset or long press after loading z80
    [main.c]
